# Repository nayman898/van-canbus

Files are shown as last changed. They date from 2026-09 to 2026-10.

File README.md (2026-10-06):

# Van CAN bus

A build-in-progress engine monitoring system for a **1982 Ford E-350**.
This repository contains the STM32 firmware, a laptop dashboard, and wiring
notes so others can follow along with the build.

The native [Android dashboard](android-app/README.md) connects a BTT U2C
directly to a phone or head unit over USB Host, without requiring a laptop or
Raspberry Pi in the vehicle.

[GitHub Actions](docs/automation.md) tests the host tools and CAN encoders,
builds both firmware configurations and the Android APK, and publishes the
generated wiki after successful pushes to `main`. Build downloads are attached
to each workflow run.

The first node uses an ST NUCLEO-G0B1RE and an Adafruit CAN Pal transceiver.
A BTT U2C V2.1 connects the bus to either the Android app or laptop. This is a
custom telemetry network, not an OBD-II scanner or decoder for a factory
vehicle network.

The current bench firmware transmits a Classical CAN heartbeat and two TX3
coolant-temperature inputs (pre- and post-radiator) at 500 kbit/s.

The provisional vehicle wiring and connector allocation are documented in
[the engine-node harness plan](docs/engine-node-harness.md).
It does not control the engine, fuel system, cooling fans, or any other output.
The node actively transmits its own CAN messages; “read-only engine monitoring”
does not mean CAN listen-only mode.

## How it fits together

```mermaid
flowchart LR
    TX3[TX3 coolant sensor] -->|Analog voltage| MCU[NUCLEO-G0B1RE]
    MCU -->|CAN TX / RX| PAL[Adafruit CAN Pal]
    PAL <-->|CAN-H / CAN-L + ground| U2C[BTT U2C V2.1]
    U2C <-->|USB| HOST[Android app or laptop dashboard]
```

The Nucleo samples the sensor and encodes the messages. The CAN Pal provides
the physical CAN interface; the U2C bridges the bus to Android or the laptop.
The working bench setup uses USB power for the Nucleo and U2C.

## Current status

| Area | What exists today |
| --- | --- |
| CAN and coolant channel 1 | Working on the bench at 500 kbit/s |
| Android app | Native U2C dashboard, raw-frame view, and CSV logging |
| Laptop tools | Terminal monitor and live browser dashboard |
| Vehicle harness | Provisional 6-pin power/CAN and 12-pin sensor allocations |
| Vehicle power | Protection parts selected; assembly/vehicle validation still pending in the build notes |
| Coolant channel 2 | Two-channel firmware flashed/verified; phone operation confirmed and both readings received on PC |
| Additional sensors | Pressure inputs planned |
| Recording | Raw-frame CSV recording and export in the Android app |

## Follow the build

| Guide | What it covers |
| --- | --- |
| [Documentation index](docs/README.md) | Suggested reading and build order |
| [Build progress](docs/build-progress.md) | Completed milestones, design choices, and next steps |
| [Hardware](docs/hardware.md) | Bench parts, sensor circuit, and hardware references |
| [Bench setup](docs/bench-setup.md) | Wiring, first power-up, expected readings, and troubleshooting |
| [Harness and vehicle power](docs/engine-node-harness.md) | Connector assignments and staged power-input work |
| [Firmware](docs/firmware.md) | Build, programming, and source walkthrough |
| [CAN protocol](docs/can-protocol.md) | Message layouts, units, fault flags, and examples |
| [Laptop tools](tools/README.md) | Dashboard, terminal monitor, setup, and limitations |
| [Android app](android-app/README.md) | Direct U2C connection, phone setup, and logging |

## Bench wiring

| Nucleo / CAN Pal | Connection |
| --- | --- |
| Nucleo 3V3 | CAN Pal Vcc |
| Nucleo GND | CAN Pal GND |
| Nucleo PA12 / FDCAN1_TX | CAN Pal TX |
| Nucleo PA11 / FDCAN1_RX | CAN Pal RX |
| CAN Pal SLNT | GND |
| CAN Pal H | U2C H |
| CAN Pal L | U2C L |
| CAN Pal terminal GND | U2C GND |

Leave the U2C V+ terminal disconnected. Enable one 120-ohm terminator at each
end. With all USB cables unplugged, CAN-H to CAN-L should measure about 60 ohms.

## Firmware behavior

- Bus: Classical CAN, 500 kbit/s
- Heartbeat identifier: standard 11-bit ID `0x100`
- Period: 500 ms
- Payload: protocol, node, status, sequence, and 32-bit little-endian uptime
- Nucleo LED PA5 toggles whenever a heartbeat is successfully queued
- Coolant identifiers: `0x110` pre-radiator, `0x111` post-radiator (standard 11-bit)
- Coolant period: 250 ms per sensor
- Coolant inputs: pre-radiator A0 / PA0 / ADC1_IN0; post-radiator A1 / PA1 / ADC1_IN1
- TX3 pull-up: nominal 2.47 kohm to 3.3 V

| Byte | Meaning |
| ---: | --- |
| 0 | Protocol version (`1`) |
| 1 | Node type (`1` = engine node) |
| 2 | Status (`0x01` = bench-test firmware) |
| 3 | Rolling sequence counter |
| 4-7 | Uptime in milliseconds, little-endian |

Coolant frames `0x110` and `0x111`:

| Byte | Meaning |
| ---: | --- |
| 0 | Protocol version (`1`) |
| 1 | Sensor (`1` = pre-radiator, `2` = post-radiator) |
| 2 | Status (`0` valid, bit 0 open, bit 1 short, bit 2 ADC, bit 3 calculation) |
| 3 | Rolling sequence counter |
| 4-5 | Averaged 12-bit ADC count, little-endian |
| 6-7 | Signed temperature in 0.1 degrees C, little-endian; `-32768` if invalid |

The temperature conversion uses a three-point Steinhart-Hart fit for the TX3:
9335 ohms at 0 C, 3500 ohms at 20 C, and 336 ohms at 80 C. Update
`TX3_PULLUP_OHMS` in `Inc/tx3_sensor.h` if the measured pull-up differs from
2470 ohms.

## Clone and build

Clone the repository, then initialize the pinned STM32CubeG0 dependency and
only the two nested ST driver modules this firmware uses:

```powershell
git clone https://github.com/nayman898/van-canbus.git
cd van-canbus
git submodule update --init --depth 1 third_party/STM32CubeG0
git -C third_party/STM32CubeG0 submodule update --init --depth 1 Drivers/STM32G0xx_HAL_Driver Drivers/CMSIS/Device/ST/STM32G0xx
```

From STM32CubeIDE for VS Code, select the `Debug` CMake preset and build. The
build creates `.elf`, `.hex`, and `.bin` images under `build/Debug`.

## Laptop monitor

Install Python 3.10 or newer, create a virtual environment, and install the monitor's
dependencies:

```powershell
py -3 -m venv .venv
.\.venv\Scripts\python -m pip install -r requirements.txt
.\.venv\Scripts\python tools\monitor_can.py
```

The U2C must use its normal `CAN OUT` H/L/GND connection and its `120R` jumper.

For a graphical dashboard, run:

```powershell
.\.venv\Scripts\python tools\can_dashboard.py
```

The dashboard opens at `http://127.0.0.1:8765` and displays live coolant
temperature, ADC voltage, sensor faults, node uptime, and CAN connection state.
It automatically retries if the USB CAN adapter is temporarily disconnected.
On Windows, `start_dashboard.bat` provides a one-click launcher after the Python
environment has been installed.

The dashboard displays live readings and retains the latest values in memory;
it does not save recordings. See the [tools guide](tools/README.md) for options,
troubleshooting, and a way to capture a basic terminal transcript.

Run the host-side protocol decoder tests with:

```powershell
.\.venv\Scripts\python -m unittest discover -s tests -v
```

## Safety boundary

This is bench-test firmware. Do not connect the RECOM regulator directly to
vehicle power until fused input, reverse-polarity protection, and automotive
transient/load-dump protection have been added and verified.
Sensor-input transient protection and a secured harness/enclosure are also
still needed before vehicle installation.

## Questions and build feedback

Questions and observations are welcome in
[GitHub Issues](https://github.com/nayman898/van-canbus/issues). Include the board
and adapter versions, firmware commit, wiring, and observed behavior so your
setup can be compared with this one.

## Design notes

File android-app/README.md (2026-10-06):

# Van CAN Android dashboard

Native, receive-only Android dashboard for the van's project-owned CAN network.
It connects directly to the BTT U2C over Android USB Host, so the first version
does not require a laptop or Raspberry Pi in the vehicle.

## Current capabilities

- Direct GS_USB/candleLight connection to the U2C at **500 kbit/s**.
- Decodes engine heartbeat `0x100`, pre-radiator coolant `0x110`, and
  post-radiator coolant `0x111` (both TX3 sensors).
- Shows two independent temperature cards, stacked on phones and side-by-side
  in wide landscape layouts; fault and stale status are per sensor.
- Shows coolant in °F/°C, ADC count, estimated signal voltage, node uptime,
  frame rate, heartbeat sequence, and recent raw CAN frames.
- Records every received frame to CSV and exports it with Android's document
  picker.
- Responsive custom dashboard for a phone in portrait or the ESSGOO display in
  landscape.
- System-bar and camera-cutout spacing, larger phone readings and controls,
  compact sensor/node cards, and scrolling when the window is too short.
- Requires no Google services and no third-party runtime library.

The application never submits a CAN data frame. The U2C is deliberately started
in normal CAN mode—not listen-only—because it must provide the CAN ACK bit when
the Nucleo and U2C are the only two active nodes.

## Open and run it

### Install a built APK

From a successful GitHub Actions run, download `android-debug-<commit>` and
extract `app-debug.apk` (see [build downloads](../docs/automation.md#download-a-build)).
Copy the APK to the phone, open it, and allow installation from that source
when Android prompts. This is a debug/test app, not a Play Store release.
The supported minimum is Android 8.0 / API 26.

To update an existing installation, the signing key must match. If Android
reports a signature conflict, export any logs before uninstalling the old app:
uninstalling removes its private files. See [debug signing](../docs/automation.md#android-signing-for-repeated-phone-updates).

### Build from Android Studio

1. In Android Studio, select **Open** and choose the `android-app` directory.
2. Allow the initial Gradle sync to finish.
3. On the Pixel, enable **Developer options → Wireless debugging**.
4. In Android Studio, choose **Pair Devices Using Wi-Fi** and pair the Pixel.
5. Select the Pixel as the run target and press **Run**.

Wireless debugging keeps the Pixel's USB-C port free for the U2C. The generated
debug APK is at:

```text
app/build/outputs/apk/debug/app-debug.apk
```

## First hardware test

1. With power off, verify approximately 60 Ω between CAN-H and CAN-L on the
   complete, terminated bus.
2. Connect the U2C to CAN-H, CAN-L, and the bus reference/ground used by the
   existing bench setup. Leave the U2C `V+` terminal disconnected.
3. Disconnect the U2C from the laptop.
4. Connect it to the Pixel using a known data-capable USB-C cable. If a direct
   cable does not put the phone into USB-host mode, use a USB-C OTG/host adapter.
5. Launch **Van CAN** and grant the Android USB permission prompt.
6. Power the Nucleo setup. The status should progress from `U2C ONLINE · WAITING
   FOR CAN` to `CAN ONLINE · 500 KBIT/S` and the raw-frame list should show
   `100`, `110`, and `111` with the two-channel firmware.

Both channels were confirmed operating in the October 5–6, 2026 bench session;
this does not establish ESSGOO compatibility or calibrated temperature accuracy.
Each card hides stale temperatures after 1.5 seconds without its own message.
An absent sensor with its pull-up installed should report OPEN without
interrupting the other channel. See the [bench test](../docs/bench-setup.md#second-coolant-channel).

Do not connect vehicle 12 V to any U2C USB or `V+` pin. The U2C is powered from
the Android USB host for this arrangement.

## Logging

Press **START LOG** to create a CSV in the app's private external-files folder.
Press **STOP LOG** to finish it. **EXPORT** opens Android's document picker and
copies the latest log to a location you choose. Export also safely stops an
active log first.

Both coolant IDs are included automatically in the raw-frame CSV; no separate
logging channel needs to be enabled for the post-radiator sensor.

## Reading the dashboard

| Display | Meaning |
| --- | --- |
| Pre-radiator / `0x110` | Sensor 1, engine outlet, A0/PA0 |
| Post-radiator / `0x111` | Sensor 2, radiator outlet, A1/PA1 |
| °F / °C | Firmware-calculated temperature, not independently calibrated by the app |
| ADC / V | Averaged raw ADC count and voltage estimated using a nominal 3.3 V reference |
| VALID | Fresh message with valid protocol, identity, ADC range, and no sensor fault |
| OPEN / SHORT | Firmware input fault; temperature is hidden |
| ADC ERROR / CALC ERROR | Acquisition or conversion failed; temperature is hidden |
| STALE / NO DATA | No fresh message for this sensor, or USB is disconnected |
| Engine node | Heartbeat status, node uptime, frame count/rate, heartbeat sequence |
| Raw CAN | Recent frames, including `100`, `110`, and `111` |

The header reports overall traffic; one healthy sensor does not establish that
the other is fresh. On a quiet bus, expect roughly ten received frames/second.
The controls are **CONNECT/DISCONNECT**, **START/STOP LOG**, and **EXPORT**.
On shorter screens, scroll to reach the raw frames and controls. No fan or
engine-control commands are implemented by this app.

## Troubleshooting

| Problem | Check |
| --- | --- |
| U2C not detected | USB data cable, host/OTG mode, supported USB identity, and connection to this device rather than the PC |
| USB permission denied | Reconnect, press CONNECT, and grant Android's USB permission |
| U2C online but waiting for CAN | Node power, shared reference, 500-kbit/s bus, wiring, and termination |
| Only pre-radiator appears | Install the two-card app build; flash the two-channel firmware and check for `111` in Raw CAN |
| Post-radiator shows OPEN | Check sensor 2 wiring/return and its separate divider; an installed pull-up without a sensor produces OPEN |
| One card becomes stale while the other updates | Check whether that channel's CAN ID continues arriving; freshness is independent |
| Works on phone but not PC | Move the U2C to the PC and restart the [Python dashboard backend](../tools/README.md#restart-after-updating-the-code) |
| APK will not update existing app | Check signing-key compatibility; export logs before any uninstall |
| Head-unit USB works for Android Auto but not Van CAN | The vendor may reserve that port; ordinary app USB Host access is not yet confirmed |

For resistance/continuity checks, remove power first and follow the
[bench guide](../docs/bench-setup.md). A functioning display does not validate
automotive power protection or temperature accuracy.

## ESSGOO head-unit test

Build and verify on the Pixel first, then copy/install the same APK on the
ESSGOO unit. Android version differences are covered by the app's API 26 minimum.
The remaining unknown is whether the ESSGOO firmware exposes its rear Android
Auto USB port to ordinary USB Host applications. The app will show `U2C not
detected` if that port is reserved by the vendor firmware.

## USB identities

Automatic detection currently accepts the two standard GS_USB identities:

| VID:PID | Family |
| --- | --- |
| `1D50:606F` | Geschwister Schneider / common GS_USB |
| `1209:2323` | candleLight |

If the BTT firmware reports a different identity, capture it with Android's
USB Device Info app or `adb shell dumpsys usb`, then add it in both
`GsUsbCanAdapter.isSupported()` and `res/xml/usb_device_filter.xml`.

## Project layout

- `MainActivity.java` — permission, USB lifecycle, decoding, logging, export.
- `usb/GsUsbCanAdapter.java` — direct GS_USB control and bulk transfers.
- `protocol/VanCanDecoder.java` — project CAN payload decoder.
- `DashboardView.java` — phone/head-unit responsive display.
- `logging/CsvCanLogger.java` — raw-frame CSV logger.

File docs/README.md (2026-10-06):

# Build documentation

[Project home](../README.md)

These notes describe the engine-monitoring system as it is being built. A
working bench circuit, a proposed vehicle circuit, and a reserved connector pin
are different stages of the project; each guide identifies which it describes.

## If you want to see how it is being built

Start with [build progress](build-progress.md), then read the
[hardware guide](hardware.md) and [harness plan](engine-node-harness.md).
They cover the parts, the first sensor circuit, the two-plug layout, and the
work still needed before installation.

## If you want to reproduce the bench setup

1. Gather the [bench hardware](hardware.md#bench-parts).
2. Clone and build the [firmware](firmware.md).
3. Follow the [bench wiring and bring-up](bench-setup.md).
4. Install and start the [laptop tools](../tools/README.md).
5. Compare the readings with the [CAN protocol](can-protocol.md).

For direct phone viewing without a PC or Pi, use the
[Android app guide](../android-app/README.md): APK installation, U2C connection,
two-temperature display, CSV logging/export, and troubleshooting. In the wiki,
this is the **Android dashboard** sidebar entry (`Android-App`).

Vehicle-power tests are a later stage in the [harness plan](engine-node-harness.md),
not a prerequisite for reproducing the USB-powered bench network.

## Where to find each kind of information

| Information | Maintained in |
| --- | --- |
| Parts and sensor circuit | [Hardware](hardware.md) |
| Board-to-board bench wiring | [Bench setup](bench-setup.md) |
| External connector cavity assignments | [Harness plan](engine-node-harness.md) |
| Firmware build and source organization | [Firmware](firmware.md) |
| CAN IDs and byte layouts | [CAN protocol](can-protocol.md) |
| Python commands and dashboard behavior | [Laptop tools](../tools/README.md) |
| Completed work and open design decisions | [Build progress](build-progress.md) |
| Phone dashboard and CSV recording | [Android app](../android-app/README.md) |
| Automated tests, build downloads, and maintenance | [Automation](automation.md) |
| Generated GitHub wiki | [Wiki publishing](wiki-publishing.md) |

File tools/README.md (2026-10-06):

# Laptop monitor and dashboard

[Project home](../README.md) · [Bench setup](../docs/bench-setup.md) · [Protocol](../docs/can-protocol.md)

The Python tools read the project's CAN messages through a BTT U2C V2.1 using
the `gs_usb` interface. Windows is the documented working host setup. The
adapter needs compatible firmware and a USB backend/driver accessible to
PyUSB; the tools do not flash the adapter or install its Windows driver.

## Install on Windows

Use Python 3.10 or newer. Run these commands from the repository root in
PowerShell:

```powershell
py -3 -m venv .venv
.\.venv\Scripts\python -m pip install -r requirements.txt
```

The requirements pin `python-can[gs-usb]` and `libusb-package`. The monitor
initializes the bundled libusb backend before loading the CAN interface, so
Windows does not need to provide that DLL itself. This does not replace the
USB device driver requirement.

## Browser dashboard

```powershell
.\.venv\Scripts\python tools\can_dashboard.py
```

After the first setup, double-click `start_dashboard.bat` to run the same app.
It serves the dashboard on `http://127.0.0.1:8765` and opens the default browser.
Keep its terminal open while using it; press **Ctrl+C** there to stop the server
and release the adapter. Closing the browser tab alone does not stop the app.

The dashboard displays both pre-radiator (`0x110`) and post-radiator (`0x111`)
coolant temperatures in °F/°C, independent fault/stale status, estimated sensor voltage,
ADC count, sensor faults, heartbeat uptime/sequence, frame count, and the age
of the last received frame. The browser polls the backend every 250 ms.

| Connection label | Meaning |
| --- | --- |
| `CAN live` | Adapter connected and a frame received within the last 1.5 seconds |
| `Waiting for CAN data` | Adapter connected, but no recent frame |
| `U2C disconnected` | The backend could not open or continue reading the adapter |
| `Dashboard backend unavailable` | Browser could not fetch the local server state |

The backend retries adapter errors every two seconds. Each temperature card
tracks its own message age and hides its temperature after 1.5 seconds without
an update, on a sensor fault, or when disconnected. Backend fetch failures
also clear both displayed temperatures. Traffic from one sensor does not keep
the other sensor's reading fresh. The header follows overall CAN traffic.

### Restart after updating the code

Stop the existing dashboard with **Ctrl+C in its terminal**, then launch
`start_dashboard.bat` again and refresh the browser. Refreshing or closing a
browser tab does not restart Python or load changed backend code. Run only
one dashboard/monitor against the U2C at a time, and move its USB connection
from the phone to the PC when switching hosts.

At `http://127.0.0.1:8765/api/state`, the two-channel backend has `coolant`
(pre-radiator) and `coolant_post` (post-radiator), each with `valid` and
`age_ms`. A response lacking `coolant_post` indicates old backend code.
On a quiet healthy bus, expect about ten frames/s: four per sensor plus
two heartbeats. Check that frame count rises and ages stay low, rather than
trusting an old `connected: true` value alone.

## Terminal monitor

Stop the dashboard first, then run:

```powershell
.\.venv\Scripts\python tools\monitor_can.py
```

It prints received timestamps, decoded heartbeat/coolant messages, and other
frames in python-can's text format. Press **Ctrl+C** to stop it. Unlike the
dashboard, the terminal monitor exits on adapter errors instead of retrying.

## Options

Both tools accept:

| Option | Default | Purpose |
| --- | --- | --- |
| `--bitrate` | `500000` | CAN bus bitrate; must match the node |
| `--index` | `0` | gs_usb adapter index |

The dashboard also accepts:

| Option | Default | Purpose |
| --- | --- | --- |
| `--host` | `127.0.0.1` | HTTP bind address |
| `--port` | `8765` | HTTP port |
| `--no-browser` | Off | Run without automatically opening a browser |

Example, using another HTTP port:

```powershell
.\.venv\Scripts\python tools\can_dashboard.py --port 8766 --no-browser
```

The server is local-only by default and has no authentication. Keep that
default for the laptop bench setup.

## Live monitoring and recording

The dashboard stores only its latest readings and session counters in memory.
It does **not** save a CSV, raw CAN log, or replayable recording. The terminal
monitor likewise prints to the console without creating a file.

For a basic text transcript, PowerShell can capture the terminal output:

```powershell
.\.venv\Scripts\python -u tools\monitor_can.py | Tee-Object -FilePath can-session.txt
```

Use a new filename for each session; this command overwrites that filename.
This is decoded console output, not a structured CAN recording or a playback
format. Do not run it alongside the dashboard against the same adapter.

## Troubleshooting

| Problem | Next check |
| --- | --- |
| Missing Python module | Install requirements with the same `.venv` interpreter used to launch the tool |
| Bundled libusb backend could not be loaded | Reinstall the pinned requirements and check Python/package compatibility |
| Adapter unavailable | Check USB data cable, compatible adapter firmware/driver, index, and other running CAN apps |
| Port already in use | Open the existing dashboard, stop its terminal, or choose another HTTP port |
| Server works but no frames | Follow the wiring, termination, and bitrate checks in the bench guide |
| Need the adapter's error details | Inspect `http://127.0.0.1:8765/api/state`; the backend includes an `error` field |

The scripts currently select `gs_usb` explicitly. A Linux SocketCAN setup or
Raspberry Pi deployment would need its own documented configuration; there is
no `--interface socketcan` option in these tools today.

## Decoder tests

From the repository root:

```powershell
.\.venv\Scripts\python -m unittest discover -s tests -v
```

The tests decode fixed payloads without opening the USB adapter. They still
require the installed Python dependencies because they import the monitor.

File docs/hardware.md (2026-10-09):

# Engine-node hardware

[Documentation index](README.md) · [Next: bench setup](bench-setup.md)

The first node uses development boards and a small discrete sensor circuit.
There is no custom PCB or finalized enclosure design in this repository yet.

## Bench parts

| Quantity | Part | Role |
| ---: | --- | --- |
| 1 | ST NUCLEO-G0B1RE | Runs the firmware and samples the sensor |
| 1 | Adafruit CAN Pal | Connects the MCU's CAN peripheral to the CAN wires |
| 1 | BTT U2C V2.1 with candleLight/gs_usb-compatible firmware | Laptop USB-to-CAN interface |
| 2 | TX3 coolant thermistors | Pre-radiator and post-radiator inputs |
| 2 each | 2.00 kohm and 470 ohm resistors | Separate nominal 2.47 kohm pull-up for each sensor |
| 2 | 1 kohm resistors | Separate series resistor into A0 and A1 |
| 2 | 100 nF ceramic capacitors | ADC input filtering to ground, one per channel |
| 2 total | 120-ohm CAN terminators | One at each bus end; use the boards' termination facilities |
| As needed | USB data cables, hookup wire, prototyping board | Power, programming, and assembly |
| 1 | Multimeter | Continuity, resistance, and voltage checks |

The two terminators are the total for this bench bus, not two extra resistors
to add when board termination is already enabled. Detailed interconnects are in
[bench setup](bench-setup.md).

## First coolant input

The TX3 is used as a two-wire thermistor. Its resistance and the pull-up form a
voltage divider. The MCU reads the divider through a 1-kohm series resistor.

```text
Nucleo 3V3
    |
  2.00 kohm
    |
   470 ohm
    |
    +-------- 1 kohm -------- A0 / PA0 / ADC1_IN0
    |
 TX3 thermistor
    |
dedicated sensor return ----- Nucleo GND
```

This is the bench circuit. The 1-kohm resistor alone is not a complete
automotive transient-protection circuit. The vehicle sensor-input protection
is still to be designed and added.

The thermistor itself is not polarized. Keep a consistent signal/return wire
assignment, with the return carried back to the engine node rather than using
the engine block as the sensor return. The reserved 5 V supply in the future
sensor connector is for active sensors; this TX3 divider uses **3.3 V**.

The current code assumes a 2470-ohm pull-up. If the measured combination differs,
update `TX3_PULLUP_OHMS` in [tx3_sensor.h](../Inc/tx3_sensor.h). The conversion
in [tx3_sensor.c](../Src/tx3_sensor.c) uses these three fit points:

| Temperature | Resistance used by the firmware fit |
| ---: | ---: |
| 0 °C | 9335 ohms |
| 20 °C | 3500 ohms |
| 80 °C | 336 ohms |

These are the project's current calibration assumptions, not a guarantee for
every replacement sensor. Compare your sensor with an independent temperature
measurement before relying on its readings. The firmware averages 32 ADC
samples and reports both the raw count and calculated temperature.

## Second coolant input

Duplicate the first divider on **A1/PA1/ADC1_IN1** for post-radiator coolant.
Do not share its signal junction or pull-up with A0. Both sensors use the same
conversion constants and nominal pull-up value. Add the 100 nF filter from
each ADC pin to ground, after that channel's 1-kohm series resistor.
See [second-channel wiring and tests](bench-setup.md#second-coolant-channel).

## Vehicle hardware in preparation

The [harness plan](engine-node-harness.md) contains the purchased power-stage
parts and staged test procedure: series diode, surge resistor, TVS, input
capacitors, and a RECOM R-78K5.0-1.0 converter. Their selection is not a record
of completed vehicle-transient testing.

The intended external connections are:

- **C1, 6-pin:** power, ground, CAN-H, CAN-L, reserved wake, and a spare.
- **C2, 12-pin:** coolant inputs/returns, future active-sensor power/return,
  pressure signals, and spares.

Both connector sizes are now available for the build. Their exact housing part
numbers, contact selection, face orientation, and mounting details still need
to be recorded. Follow the provisional cavity tables in the harness plan; do
not infer physical cavity positions from a generic connector picture.

Both TX3 channels are implemented and bench reception is confirmed. GlowShift
pressure inputs remain planned; reserved pins do not imply working pressure
input circuits or firmware support.

## Printable bottom guards — first fit prototypes

These are **open-top bench guards**, not sealed, automotive-qualified boxes.
They protect the underside from a flat work surface; open sides/top do not
exclude loose wire strands, tools, moisture, or metal debris. Remove the board
before soldering, drilling, or tapping plastic. Do not pot the electronics or
lay solder joints directly on the floor.

Top-view preview of the printable guards

| Board | Printable file | Dimensions / mounting |
| --- | --- | --- |
| EPLZON pictured 1.5 × 2 inch board | [Bottom tray STL](../hardware/protective-plates/stl/eplzon_38x51_tray.stl) | 43.3 × 56 × 8.4 mm; two central M3 locations, 40.6 mm apart |
| Adafruit Perma-Proto half, product 1609 | [Bottom tray STL](../hardware/protective-plates/stl/permaproto_half_1609_tray.stl) | 56 × 86.48 × 8.4 mm; two M3 locations, 73.66 mm apart |
| Nucleo MB1360, intact ST-Link, measured 8 mm pins | [Edge-retaining tray STL](../hardware/protective-plates/stl/nucleo_edge_tray_8mm_pins.stl) | 88 × 89.5 × 15.6 mm; 70 × 82.5 mm PCB, no board screws |
| Nucleo removable front stops | [Left STL](../hardware/protective-plates/stl/nucleo_stop_left.stl), [right STL](../hardware/protective-plates/stl/nucleo_stop_right.stl) | Print one each; two M3 × 6 mm screws into the tray, not the PCB |

All dimensions are millimetres. Import at **100% scale**, flat bottom on the
bed, with posts/spacers upright. The proto trays provide 6 mm from floor top
to PCB underside, a 2.4 mm floor, 2 mm low guards, and 12 mm wire notches on
all sides. Wires can also leave over the low rim. These notches are not strain
relief: secure cables separately without pulling on solder joints.

### Print and fit the proto trays

1. Print the small [EPLZON hole-spacing test](../hardware/protective-plates/stl/eplzon_38x51_fit_test.stl)
   and [Perma-Proto hole-spacing test](../hardware/protective-plates/stl/permaproto_half_1609_fit_test.stl)
   first. They are 1.2 mm-thick rails for checking hole alignment and pilot-hole
   print quality, **not electrical bottom protectors**. Check against the
   unpowered board's component side or use a paper template so the rail does
   not press on solder joints.
2. Print the full tray in ordinary, non-conductive **PETG for the bench**.
   Start with a 0.4 mm nozzle, 0.20 mm layers, four walls, five top/bottom
   layers, 20–30% infill, no supports. Use your filament maker's temperature
   profile and your CC2's calibrated flow settings; no printer-specific G-code
   is supplied. Use a brim if needed for adhesion.
3. Posts have **2.7 mm blind pilots**, intended for gently tapping M3 threads
   or carefully forming them with a machine screw. Test on scrap first.
   Start with M3 × 6 mm screws for a nominal 1.6 mm PCB; verify actual engagement
   and do not bottom out. Prefer nylon screws; if using metal, ensure the head
   and any washer stay within the mechanical-hole keepout. Do not overtighten.
4. The EPLZON tray uses the two **central 3.2 mm holes**, NOT the four M2 corner
   holes. The mounting posts touch a 6 mm-diameter area around each hole: check
   that this area has no soldered lead or component on your actual board.
5. Measure the longest underside solder/wire projection. With 6 mm supports,
   keep it below 4 mm to retain at least 2 mm of clearance. If it is longer,
   increase `clearance` in the model rather than forcing the board down.
6. Confirm the board is supported only at its mounting points, is not bowed,
   and does not rock. The two-post arrangement is a bench prototype, not
   validated support for heavy components or vehicle vibration.

### Nucleo: edge-retaining tray for 8 mm bottom pins

The user supplied the MB1360 mechanical drawing (70 × 82.5 mm) and measured
8 mm pin projection. The PCB underside is therefore **10 mm above the floor**,
leaving **2 mm nominal pin clearance**. Keep the ST-Link section attached.
There are no assumed PCB mounting holes: the rails support/capture its long
edges and two removable front corner stops prevent sliding out.

1. Print the [full-width rail-fit coupon](../hardware/protective-plates/stl/nucleo_rail_fit_test.stl)
   first. It has the same rail spacing, clearance, and 2.0 mm slot as the full
   tray, but is only 12 mm long. The slot assumes 1.6 mm PCB thickness plus
   0.4 mm vertical allowance; width clearance is 0.5 mm per side.
2. With **all power/cables removed**, inspect the outer 0.8 mm strip along both
   long edges, on both faces. It must be free of components, solder, wiring,
   and protruding header plastic where the lips/supports contact. Sideways
   board play can increase contact overlap to about 1.3 mm on one side; check
   that wider strip too. The supplied top drawing does not establish underside
   keepouts. Do not force the coupon or tray past a connector or solder joint.
3. Print the tray and one of each front stop, using the PETG settings above.
   Flat bases go on the bed; lips are only 1.3 mm overhangs and are intended to
   print without supports. Inspect the slicer's layers and remove any droop
   before test-fitting. Do not scale the entire model to correct a tight slot.
4. Before inserting the board, tap/check the tray's two 2.7 mm blind pilots.
   The rail opening is the end with the two low screw pads. Slide the **non-USB
   end first** toward the far stop, keeping the USB/ST-Link end at the opening.
   Headers, pins and solder joints must stay clear during the entire slide.
5. Install the left/right corner stops on their screw pads with **M3 × 6 mm**
   screws. Their raised tabs face inward and the open/USB end. They attach to
   plastic only and leave the central USB area open. Do not tighten them onto
   the board; leave its small designed clearance. Check the actual USB plug's
   moulded body clears the tray before plugging in.
6. Verify the lowest pin still clears the floor by at least 2 mm, the board
   cannot slide out or lift free, and no plastic contacts solder or components.
   Only then reconnect power. Remove both stops before sliding the PCB out.

Edit [nucleo.json](../hardware/protective-plates/nucleo.json) if the board
thickness, edge keepouts, or pin length differs. This is a **first-fit bench
prototype**, not physically verified or approved for vibration/underhood use.
The older drill-to-fit blank and separate spacers remain as legacy files; they
are not needed for this tray, and electrical header holes must never be used
as screw mounts. No drilling or cutting of the Nucleo is required.

### Material and enclosure limits

PETG is a practical first fit/bench material; ASA offers better heat/UV
resistance but needs suitable ventilation and a tuned enclosed-printer profile.
See the [manufacturer material guide](https://help.prusa3d.com/filament-material-guide).
Neither material name alone establishes suitability underhood: check the exact
filament datasheet, measured location temperature, hot components, fluid
exposure, and vibration. Avoid conductive/ESD filament. Keep hot diodes and
the surge resistor clear of plastic and maintain their thermal clearance.

Full lids and sealed cable entries are deferred until we measure the populated
component heights, wire bundle sizes, USB access, and mounting location. These
prints are not waterproof, flame-rated electrical enclosures, or a replacement
for the planned protected vehicle power stage.

### Editable source and verification

#### Fusion / Onshape solid CAD files

- [Nucleo STEP assembly — original 2.7 mm pilots](../hardware/protective-plates/step/pilot_2.70mm/nucleo_assembled.step)
- [Nucleo STEP assembly — 2.5 mm M3-tap pilots](../hardware/protective-plates/step/pilot_2.50mm/nucleo_assembled.step)

Each assembly's directory includes individual **STEP solids** for both proto trays, the Nucleo
tray and left/right stops, and the fit-test pieces. `nucleo_assembled.step`
contains the tray and stops in their assembled positions as three separate
solids; use individual part files when preparing prints. Each directory also
contains a validation report. Editable generator source/JSON and dependency
lists are in `hardware/protective-plates/`.

Generated ZIP bundles are excluded from Git because they duplicate the tracked
CAD files, sources, and hardware guide. The STEP and mount generators below
still create local ZIP bundles when you need to share a complete set.

These are analytic CAD bodies, not STL-to-solid conversions. STEP does **not**
preserve the original Fusion timeline, Onshape sketches/constraints, or named
parameters. Native `.f3d` / Onshape documents are not generated here. After
import, use direct face edits or add sketches and features, then save in your
application's native format. For linked dimensional changes, edit the supplied
JSON/source and regenerate instead of expecting imported feature history.

- **Fusion:** download and open/upload the desired `.step` as a CAD design
  (not Insert Mesh), edit the solid bodies, and save your own Fusion document.
- **Onshape:** import the downloaded `.step` into a document; edit its solid
  parts with direct-edit features or new sketches. See
  [Onshape's import/edit guide](https://www.onshape.com/en/resource-center/tech-tips/import-edit-step-iges-parasolid-stl).
- Units are **mm**. Check the Nucleo tray is 88 × 89.5 × 15.6 mm after import.

The 2.5 mm variant changes only the blind pilots and matching pilot test holes;
the stops' 3.3 mm clearance holes remain unchanged. It has no modelled threads:
finish the printed pilots to the tap manufacturer's drill size, then tap M3 ×
0.5 without breaking through the floor. Test blind-hole thread depth on scrap
and account for the tap's lead. STEP exports do not overwrite existing STLs;
export new STLs from CAD if printing the tap-size version.

To regenerate STEP (Python 3.12+, preferably in a separate virtual environment):

```sh
python -m pip install -r hardware/protective-plates/requirements-step.txt
python hardware/protective-plates/export_step.py
python hardware/protective-plates/export_step.py --pilot-diameter 2.5
```

[STEP exporter](../hardware/protective-plates/export_step.py) reuses the original
geometry recipe with an OpenCascade solid backend. Each exported part is
re-imported and checked for validity, solid count, volume, dimensions, and
analytic cylindrical holes. Assembly import is checked for three valid solids.
Fusion/Onshape UI import and physical print fit have not been tested here.

#### Parametric dimensions and STL regeneration

Board dimensions and hole coordinates are in [boards.json](../hardware/protective-plates/boards.json).
The image supplied for the EPLZON gives 38.1 × 50.8 mm and a central hole span
of 40.6 mm. The Perma-Proto uses the exact 81.28 × 50.8 mm outline and
73.66 mm span from [Adafruit's PCB layout](https://github.com/adafruit/Adafruit-Perma-Proto-PCB),
rather than rounded shop dimensions. Its long axis is Y in this model.
Physical board revision, solder clearance, and printer shrinkage still need
checking. Do not scale the whole part to change screw-hole size.

With Python 3.12+:

```sh
python -m pip install -r hardware/protective-plates/requirements.txt
python hardware/protective-plates/generate.py
```

[The generator](../hardware/protective-plates/generate.py) produces the STLs,
preview, and [validation report](../hardware/protective-plates/validation.json).
It checks each mesh for watertightness, consistent winding, positive volume,
a single connected solid, and placement on Z=0. The Nucleo tray and assembled
stops also pass collision checks against the nominal PCB and an 8 mm-deep
central pin envelope (excluding the edge-contact strips). **These are digital geometry
checks, not physical fit tests.**

## Hammond 1554UA2GY Nucleo carrier — V2

Use this revision instead of the sliding Nucleo tray above when mounting in
the Hammond case. The photos suggest the board was sitting above the old
rail channel, leaving the end stops too low. V2 removes the upper rail lips:
the board drops in vertically and two removable side retainers capture its
edges. It does **not** assume screw-hole positions in the Nucleo PCB.
The original V1 files and the two proto-board holders are unchanged.

- [Case mounting-pattern test STL](../hardware/protective-plates/hammond-v2/case_mount_fit_test.stl)
- [Carrier STL](../hardware/protective-plates/hammond-v2/carrier.stl)
- [Retainer STL — print TWO](../hardware/protective-plates/hammond-v2/retainer_print_two.stl)
- [Assembled STEP for Fusion / Onshape](../hardware/protective-plates/hammond-v2/assembled.step)
- [Parametric generator](../hardware/protective-plates/hammond_mount.py)
- [Validation results](../hardware/protective-plates/hammond-v2/validation.json)

The [Hammond mechanical drawing](https://www.hammfg.com/files/parts/pdf/1554UA2GY.pdf?v=1748872871)
identifies **four internal M3 brass inserts at 161.5 × 90 mm spacing**.
These are not the M4 lid inserts or the intermediate #6 self-tapping bosses.
The 170 × 104 × 2.4 mm carrier has four 3.6 mm clearance holes centered at
(4.25, 7), (4.25, 97), (165.75, 7), (165.75, 97), measured from one corner.
The narrower carrier avoids the lid-post corners; it is not a copy of the
full-size steel accessory panel. The Nucleo holder is shifted all the way to
the X=0 end: the outer retainer is flush with that plate edge, leaving an
80 × 104 mm area clear of the holder at the opposite end (apart from the case
mounting holes). PCB origin is (10, 10.75) mm, with its USB end facing Y=0.
All four case screws retain a 7 mm diameter vertical access envelope; use
heads/washers no larger than 7 mm. Route and strain-relieve cables separately.

### Print and fit sequence

1. Print **only the mounting-pattern test** first, flat at 100% scale.
   Check it drops onto the four internal brass-insert bosses without rocking,
   hitting the case walls, or needing screw force to align the holes.
2. Print the carrier flat and two retainers flat. Start with 0.2 mm layers,
   four walls and 30–40% infill; no supports are needed. PETG is suitable for
   bench fitting; ASA is a candidate for warmer service, but this design has
   no validated underhood temperature, vibration, or fire rating.
3. Clear the four **blind 2.5 mm pilot holes** with a depth-limited drill and
   tap M3 × 0.5. Usable pilot depth is 11.2 mm; do not drill through the floor.
   Remove all chips before placing electronics. Use four M3 × 8 mm pan-head
   screws for the retainers (5.6 mm nominal engagement through the 2.4 mm bar).
4. Drop the unpowered Nucleo onto the two narrow support edges. PCB underside
   is 10 mm above the carrier floor, giving the stated 8 mm pins 2 mm clearance.
   Confirm every pin and solder joint clears the floor and supports.
   **The outer 0.8 mm PCB edge strips must be free of pins/components**; this
   remains an unverified physical-fit assumption. Stop if either header rests
   on a rail, or the board cannot seat flat. Do not force it down.
5. Fit one retainer per side, with its overhanging edge facing the PCB. Rotate
   the second copy 180° in the plane. Two screws per bar prevent rotation.
   The design leaves 0.4 mm above a nominal 1.6 mm PCB; tighten against the
   printed posts, not against the PCB. The front corner stops and rear fence
   limit lengthwise movement. Check USB/header access before powering up.
6. Screw the carrier into the case's four **M3 brass inserts**. Hammond lists
   M3 × 8 mm screws for its panel, but our printed carrier has a different
   thickness: measure usable insert depth and select length/washer thickness
   so screws engage securely without bottoming. An M3 × 8 screw through this
   plate projects 5.6 mm before washers. Do not force a bottomed screw or use
   self-tappers in the brass inserts. No drilling through the case is required.

Check clearance to the lid with all headers, plugs and wiring installed;
board thickness, header geometry, printer shrinkage and the case itself still
need physical verification. This is a bench-fit prototype, not a certified
automotive mounting system. Mounting inside a rated case does not independently
establish a rating for the completed wired enclosure.

The STEP files contain editable analytic solids, not a native Fusion timeline
or Onshape feature tree. Import the assembly for placement or the individual
parts for direct face edits. To regenerate after changing the constants:

```sh
python -m pip install -r hardware/protective-plates/requirements-step.txt
python hardware/protective-plates/hammond_mount.py
```

The generator validates nominal PCB/pin and inter-part clearance, valid CAD
solids, STEP round trips, and watertight STL meshes. These checks do not replace
the mounting-pattern print and unpowered physical fit checks above.

## EPLZON holder with 5 × 5 mm corner contacts

This experimental alternative leaves all PCB mounting holes unused, for the
assembled board whose central holes are covered by wiring and a subboard.
Four supports and four removable corner clips overlap only the nominal
5 × 5 mm corner squares. Revised after the first print missed the corners
by approximately 1 mm: both the lower supports and upper clips now reach
3 mm farther inward than the original 2 mm version. Board spacing, screw
positions and underside clearance are unchanged; this corrects contact reach
without making the board pocket smaller. Reprint the tray/frame and four clips.
The user's clearance estimate is provisional:
**rounded PCB corners or corner holes may remove too much of that contact
area. Verify actual solid PCB material is captured before using this holder.**
Do not enlarge the contacts into wiring or solder joints to force a fit.

- [Fit-test frame](../hardware/protective-plates/eplzon-corners/fit_test_frame.stl)
- [Full bottom tray](../hardware/protective-plates/eplzon-corners/tray.stl)
- [Corner clip — print four](../hardware/protective-plates/eplzon-corners/corner_clip_print_four.stl)
- [Editable STEP assembly](../hardware/protective-plates/eplzon-corners/assembled.step)
- [Generator](../hardware/protective-plates/eplzon_corner_mount.py)

Print the fit-test frame and four clips first, flat, at 100% scale, 0.2 mm
layers and four walls. No supports are needed. Tap the eight blind 2.5 mm
post holes M3 × 0.5; two screws per clip prevent rotation. Use eight M3 × 6 mm
pan-head screws with heads no larger than 5.5 mm diameter, without washers
(3.6 mm engagement through the 2.4 mm clips). Pilot depth is
7.1 mm; depth-limit tools and clean out debris with the electronics removed.
Rotate identical clips to match each corner's two holes. Tighten against
the posts, never crush the PCB or wiring.

The tray is 54.1 × 66.8 mm with 6 mm free height under the board, except at
the four contact squares. PCB thickness is assumed to be 1.6 mm, with 0.3 mm
vertical retention clearance. Measure your longest underside solder joint
or wire: it must fit with margin in that 6 mm space. Check all four corners
seat and retain securely, without rocking or slipping past the clips. If
the rounded corners cannot be captured, stop and provide a photo for a
revised contact shape; this design is not yet physically validated.

After checking fit, substitute the solid-floor tray for underside protection.
The open frame is a fit test, not a bottom-contact guard. PETG is appropriate
for bench fitting; this is not a sealed or vehicle-qualified enclosure and
does not include mounting to the Hammond carrier. Existing center-hole trays
are unchanged. Regenerate with `python hardware/protective-plates/eplzon_corner_mount.py`
using the same STEP requirements as the Hammond holder.

## Manufacturer references

- [ST MB1360 / Nucleo-64 user manual](https://www.st.com/resource/en/user_manual/dm00452640.pdf): board power selection, connectors, and onboard ST-Link.
- [Adafruit CAN Pal pinouts](https://learn.adafruit.com/adafruit-can-pal/pinouts): transceiver pinouts and termination.

Check the documentation for your actual board revision when locating headers
or changing power jumpers.

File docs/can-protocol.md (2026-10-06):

# CAN protocol

[Documentation index](README.md) · [Firmware](firmware.md) · [Laptop tools](../tools/README.md)

This is the project's own telemetry format. The definitions are in
[can_protocol.h](../Inc/can_protocol.h) and the encoder in
[can_protocol.c](../Src/can_protocol.c).

## Bus and encoding

- Classical CAN at **500,000 bit/s**; CAN FD and bitrate switching disabled.
- Standard **11-bit** identifiers and eight-byte data payloads.
- Multi-byte integers are **little-endian**.
- Protocol version is `1`.
- Each message type has its own eight-bit sequence counter, wrapping after 255.
- Nominal periods assume normal operation; reception may be delayed or missing
  if transmission is blocked or the bus is unavailable.

## Engine heartbeat — `0x100`

Nominal period: **500 ms**.

| Byte | Field | Encoding |
| --- | --- | --- |
| 0 | Protocol version | `1` |
| 1 | Node type | `1` = engine node |
| 2 | Node status | `0x01` = bench-test firmware |
| 3 | Sequence | Unsigned eight-bit counter |
| 4–7 | Uptime | Unsigned 32-bit milliseconds since startup |

The uptime field wraps with the 32-bit tick counter. A restart resets the
uptime and sequence counters. The node status is a firmware-stage indicator,
not the coolant sensor's fault status.

Example from the decoder tests:

```text
ID 0x100    01 01 01 2A 78 56 34 12
Protocol 1, engine node 1, bench status 1, sequence 42
Uptime = 0x12345678 = 305419896 ms
```

## Coolant temperatures — `0x110` and `0x111`

Nominal period: **250 ms per sensor**, each with an independent sequence counter.

| Location | Sensor ID | CAN ID | ADC input |
| --- | --- | --- | --- |
| Pre-radiator (engine outlet) | 1 | `0x110` | A0 / PA0 / ADC1_IN0 |
| Post-radiator (radiator outlet) | 2 | `0x111` | A1 / PA1 / ADC1_IN1 |

Both are TX3 thermistors with separate 2.47-kohm pull-ups. Sensor 1 retains
its existing wire format; adding sensor 2 does not change protocol version.

| Byte | Field | Encoding |
| --- | --- | --- |
| 0 | Protocol version | `1` |
| 1 | Sensor ID | `1` = pre-radiator; `2` = post-radiator |
| 2 | Sensor status | Flags below; zero means valid |
| 3 | Sequence | Unsigned eight-bit counter |
| 4–5 | ADC reading | Unsigned 16-bit field containing the averaged 12-bit count |
| 6–7 | Temperature | Signed 16-bit integer in tenths of a degree Celsius |

On a fault, the firmware sends `-32768` (`00 80` in wire byte order) as the
invalid temperature value. Consumers should check status before displaying
temperature. Both host decoders validate status, protocol version, matching
CAN/sensor identity, ADC range, and the invalid-temperature sentinel. Each UI
tracks freshness per sensor and hides temperatures after 1.5 seconds without
that sensor's message, or when disconnected.

| Status | Meaning | Current firmware condition |
| --- | --- | --- |
| `0x00` | Valid | Conversion completed without a fault |
| `0x01` | Open circuit | ADC count >= 4050 |
| `0x02` | Short circuit | ADC count <= 16 |
| `0x04` | ADC error | ADC acquisition failed |
| `0x08` | Calculation error | Invalid/non-finite or unrepresentable conversion result |

Flags occupy individual bits, although the present firmware returns one fault
at a time. The host maps these individual values to labels; combined/unknown
values are shown as unknown status and still suppress temperature.

Example from the decoder tests:

```text
ID 0x110    01 01 00 07 32 08 0A 01
Protocol 1, sensor 1, valid, sequence 7
ADC = 0x0832 = 2098
Temperature = 0x010A = 266 tenths = 26.6 °C = 79.88 °F
```

The host's displayed voltage is `adc_raw * 3.3 / 4095`, using a nominal 3.3 V
reference. It is an estimate derived from the count, not a separate voltage
measurement. Temperature comes from the firmware's transmitted value.

For the same test reading on sensor 2, use `0x111` with payload
`01 02 00 07 32 08 0A 01`. An absent second sensor with its pull-up installed
reports an open-circuit fault; it does not suppress sensor 1.

## Planned expansion

Pressure inputs have no implemented message definitions yet.
Allocate their IDs and payloads alongside the firmware and
host changes, then update this reference. There is currently no DBC file,
configuration protocol, or vehicle-control message set.

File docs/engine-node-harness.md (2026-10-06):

# Engine node harness plan

[Documentation index](README.md) · [Bench setup](bench-setup.md) · [Hardware](hardware.md)

This is the preparation plan for the first read-only engine node. The bench
network already works at 500 kbit/s. Vehicle power and sensor inputs are not
ready to connect yet.

## Connector strategy

Keep vehicle power/CAN separate from the sensor harness. This leaves enough
sensor cavities for later oil and fuel-pressure inputs and makes either side of
the installation serviceable without disturbing the other.

Both the 6-pin and 12-pin plugs are now available for this build. The intended
allocation is [C1 for power/CAN](#c1-final-power-and-can-provisional-6-way) and
[C2 for sensors](#c2-final-sensors-provisional-12-way). Those cavity assignments
remain provisional until the housing part numbers and orientation are recorded.
The older C0 combined allocation below is retained as a temporary reference;
it is **not pin-compatible** with the sensor-only C2 allocation.

Connector names C1/C2 and capacitor references C1/C2 in the power schematic
belong to separate naming contexts in these prototype notes.

## C0: temporary combined 12-way

This was the interim allocation while the separate power/CAN connector was unavailable.
The molded cavity numbers on the connector are authoritative; do not assign
pins by apparent left/right position because the mating face and wire-entry
views are mirrored.

Typical cavity arrangement, viewed at the mating face and confirmed by the
molded numbers:

```text
  1    2    3    4    5    6
 12   11   10    9    8    7
```

| Cavity | Circuit | Suggested color | First van test |
| ---: | --- | --- | --- |
| 1 | Fused switched 12 V input | Red | **Leave unpopulated** |
| 2 | Coolant sensor 1 signal | Tan/white | TX3 at thermostat outlet |
| 3 | Coolant sensor 2 signal | Blue/white | Populate when channel 2 is built |
| 4 | Regulated 5 V sensor supply | Pink | Reserved; seal cavity |
| 5 | Ignition/wake input | Orange | Reserved; seal cavity |
| 6 | CAN-H | Yellow | Connect to U2C CAN-H |
| 7 | CAN-L | Green | Connect to U2C CAN-L |
| 8 | Spare analog/digital input | Violet | Reserved; seal cavity |
| 9 | Future active-sensor return | Gray/black | Reserved; seal cavity |
| 10 | Coolant sensor 2 return | Blue/black | Populate when channel 2 is built |
| 11 | Coolant sensor 1 return | Tan/black | Dedicated TX3 return to engine node |
| 12 | Module power/CAN reference ground | Black | Connect to U2C GND |

Pins 1/12, 2/11, 3/10, and 6/7 form vertically adjacent pairs. Keep the two
TX3 returns as dedicated conductors all the way to the module; join them to
circuit ground inside the enclosure, not at the engine or chassis. Twist pins
6 and 7 together. Carry pin 12 alongside the CAN pair as its reference.

For the first vehicle data test, power the Nucleo through USB and leave cavity
1 empty. The U2C `V+` terminal also remains disconnected. This makes the test
read-only and prevents raw vehicle power from reaching the prototype.

### Temporary harness preflight

1. Disconnect both USB cables and all vehicle connections.
2. Use continuity mode to prove every cavity end-to-end and prove that adjacent
   cavities are not shorted. Record the result by cavity number.
3. Confirm CAN-H reaches CAN-H, CAN-L reaches CAN-L, and pin 12 reaches the U2C
   ground terminal.
4. Enable one 120-ohm termination at the CAN Pal end and one at the U2C end.
   Measure approximately 60 ohms between cavities 6 and 7 with power removed.
5. Connect the two TX3 wires only to cavities 2 and 11. A TX3 thermistor is not
   polarized, but keep the assigned colors consistent at both ends.
6. Power the engine node by USB, start the dashboard, and verify heartbeat and
   room-temperature data before installing the harness in the van.

## Clean 12 V bench-supply test

This test validates the R-78K5.0 converter and external-power arrangement. It
does **not** validate an installation against reverse battery, alternator
transients, jump starts, or automotive load dump.

### Stage 1: converter by itself

1. Keep the Nucleo, CAN Pal, USB cables, and sensor board disconnected.
2. Verify the R-78K5.0 pin numbering against its datasheet before applying
   power. Do not rely on package orientation from memory.
3. Connect bench-supply positive through a small inline fuse to cavity 1 and
   supply negative to cavity 12. Use a 0.5 A fuse for this prototype test.
4. Set the supply to 12.0 V with a 0.10 A current limit, then switch it on.
5. Measure the converter input and output directly at its pins. Expect about
   12.0 V input and 5.0 V output. Switch off immediately for reversed polarity,
   current limiting, heat, odor, or an output outside 4.75--5.25 V.
6. Switch the supply off and wait for the output to fall before changing wiring.

### Stage 2: Nucleo from the converter

1. Configure Nucleo jumper JP2 to pins 5--6 for the `E5V` source, following the
   MB1360 board manual.
2. Connect converter 5 V output to the Nucleo `E5V` input and converter ground
   to Nucleo ground. Keep the ST-Link USB cable disconnected.
3. Set the bench supply to 12.0 V and a 0.25 A current limit. Power it on and
   verify 5 V and 3.3 V at the Nucleo headers before connecting the CAN Pal.
4. Connect the CAN Pal and confirm heartbeat through the independently powered
   U2C. Record steady-state input current for comparison after later changes.
5. If USB debugging is needed, apply external E5V power first and connect the
   ST-Link USB cable second, as required by the board manual.

The R-78K5.0-1.0 accepts 6.5--36 V and provides regulated 5 V at up to 1 A, but
it is not an automotive input-protection device. Do not proceed from this clean
bench test to van power until the fused reverse-polarity and transient/load-dump
stage has been selected, assembled, and tested.

## Selected protected vehicle-input stage

The following parts were purchased for the engine-node power input:

| Ref. | Part | Function |
| --- | --- | --- |
| D1 | STMicroelectronics `STPS5H100BY-TR` | 100 V, 5 A automotive Schottky series diode for reverse-battery protection |
| R1 | Vishay `PR02000201009JR500` | 10 ohm, 2 W axial surge-current limiting resistor |
| D2 | Vishay `SM8S18CAHM3/I` | 18 V standoff, 29.2 V maximum-clamp, bidirectional automotive TVS |
| C1 | Panasonic `EEH-AZC1H470B` | 47 uF, 50 V polarized hybrid input capacitor |
| C2 | TDK `FA18X7R1H104KNU00` | 0.1 uF, 50 V X7R ceramic input bypass capacitor |
| U1 | RECOM `R-78K5.0-1.0` | 6.5--36 V input to regulated 5 V converter |
| C3 | TDK `FA18X7R1H104KNU00` | 0.1 uF, 50 V ceramic output bypass capacitor |

Wire the stage in this order:

```text
switched vehicle +12 V
        |
   external 0.5 A fuse, close to source
        |
        +---- D1 anode
              D1 cathode/tab ---- R1 10 ohm ---- PROTECTED_12V ---- U1 pin 1 (+VIN)
                                                   |               U1 pin 2 (GND) ---- GND
                                                   |               U1 pin 3 (+VOUT) -- +5V
                                                   |
                                                   +---- D2 TVS ---- GND
                                                   +---- C1 47 uF -- GND
                                                   +---- C2 0.1 uF - GND

                                                     +5V ---- C3 0.1 uF ---- GND

vehicle ground -------------------------------------------------------------- GND
```

Important assembly details:

- D1's anode faces the fused vehicle input. Its cathode and metal DPAK tab face
  R1 and the converter. Confirm the physical leads with diode mode before
  soldering; the unused DPAK lead is not connected.
- D2 has a `CA` bidirectional suffix and can be installed either direction. Keep
  both of its connections short and heavy, directly between `PROTECTED_12V` and
  the power ground bus.
- C1 is polarized: positive goes to `PROTECTED_12V`, negative goes to ground.
  C2 and C3 are not polarized.
- The 10-ohm resistor intentionally limits surge current into the TVS. It also
  prevents using the converter's full nominal 1 A output at low input voltage;
  this stage is sized for the low-current engine-monitor node, not cabin loads.
- Keep CAN/sensor returns connected to the same module reference ground, but do
  not route their normal current through the TVS or capacitor lead lengths.

### Protected-input staged test

1. Disconnect the Nucleo, U2C, CAN wiring, sensors, and all USB cables.
2. With power off, verify no hard short from `PROTECTED_12V` or +5 V to ground.
3. Feed 12 V through the fuse with a 0.10 A bench current limit. Measure voltage
   before D1, after D1, at `PROTECTED_12V`, and at U1 pin 3. Expect a small drop
   across D1, almost no drop across R1 with no load, and about 5.0 V output.
4. Switch off, connect the Nucleo at E5V/GND, raise the limit to 0.25 A, and
   verify the 5 V and 3.3 V rails before reconnecting CAN.
5. For a reverse-polarity check, disconnect every USB/CAN connection, set the
   bench limit to 0.01 A, reverse the 12 V input, and verify zero converter
   output and no heating. Correct polarity before reconnecting anything.
6. Do not attempt to force the TVS into avalanche with the bench supply. Final
   installation still requires the fuse at the vehicle-power takeoff and secure,
   vibration-resistant support for the two surface-mount power parts.

### C1: final power and CAN (provisional 6-way)

| Cavity | Circuit | Suggested color |
| --- | --- | --- |
| 1 | Protected switched vehicle power | Red |
| 2 | Power ground | Black |
| 3 | CAN-H | Yellow |
| 4 | CAN-L | Green |
| 5 | Ignition/wake input, reserved | Orange |
| 6 | Spare | Violet |

The R-78K5.0 regulator must not be connected directly to vehicle power. Parts
for the protection stage are selected above; assembly and validation must
precede vehicle-power use. The table's “protected” power label does not settle
which side of C1 houses the protection stage. Record that physical placement
in the final wiring drawing before wiring cavity 1.

### C2: final sensors (provisional 12-way)

| Cavity | Circuit | Initial use |
| --- | --- | --- |
| 1 | Coolant sensor 1 signal | TX3 at thermostat outlet |
| 2 | Coolant sensor 1 return | Dedicated return to engine node |
| 3 | Coolant sensor 2 signal | TX3 at lower radiator hose |
| 4 | Coolant sensor 2 return | Dedicated return to engine node |
| 5 | Regulated 5 V sensor supply | Reserved for future active sensors |
| 6 | Active-sensor return | Reserved for future active sensors |
| 7 | Oil-pressure signal | Reserved; GlowShift interface TBD |
| 8 | EFI fuel-pressure signal | Reserved; GlowShift interface TBD |
| 9 | Carburetor fuel-pressure signal | Reserved; GlowShift interface TBD |
| 10 | Spare analog input | Reserved |
| 11 | Spare digital/frequency input | Reserved |
| 12 | Spare | Reserved |

Sensor 1 is **pre-radiator**, feeding the A0/PA0 divider; sensor 2 is
**post-radiator**, feeding its own identical divider on A1/PA1. Both use
2.47-kohm pull-ups to 3V3, separate 1-kohm ADC series resistors, and dedicated
sensor returns. See the [second-channel bench test](bench-setup.md#second-coolant-channel).
Do not confuse C2 cavities 3/4 with temporary C0 cavities 3/10.

The three GlowShift signals must not be connected until their gauge supply,
signal range, and grounding have been measured. The engine node will need a
high-impedance protected input so it does not alter the gauge readings.

## Work that is safe now

- Label both halves of each connector and all loose wires before assembly.
- Practice open-barrel crimps on spare contacts and scrap 18--22 AWG wire.
- Prepare an uncut length of twisted CAN wire. Keep CAN-H and CAN-L together at
  approximately one twist per 25 mm (one inch).
- Lay out the Nucleo, CAN Pal, and Perma-Proto inside the enclosure and measure
  for a removable ASA mounting tray.
- Plan for the enclosure vent to face downward when installed.
- Keep a service loop at the enclosure rather than cutting the vehicle harness
  to its final length on the bench.

## Work to defer

- Do not solder Deutsch/AT-series crimp contacts. Crimp them only; solder can
  wick up the conductor and create a vibration failure point.
- The first TX3 bench channel uses a nominal 2.47-kohm pull-up to 3.3 V, a
  1-kohm series resistor into A0/PA0, and firmware open/short detection. Add
  automotive transient clamps before vehicle installation.
- Do not drill the enclosure until the connector housing part numbers,
  orientation, mounting tray, and cable-exit direction are confirmed.
- Do not connect the R-78K5.0 regulator or Nucleo directly to van power.
- Do not connect or tap the GlowShift pressure-sensor wiring yet.

## Bench wiring retained for the next test

| Nucleo | CAN Pal |
| --- | --- |
| 3V3 | Vcc |
| GND | GND and SLNT |
| PA12 / FDCAN1_TX | TX |
| PA11 / FDCAN1_RX | RX |

Continue powering the Nucleo by USB for bench testing. The first TX3 channel has
been verified at 1.69 V with a room-temperature sensor near 2.60 kohm. The
vehicle installation still requires the protected power-input stage and
automotive transient protection on the sensor input.

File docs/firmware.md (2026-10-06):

# Firmware build and source guide

[Documentation index](README.md) · [CAN protocol](can-protocol.md)

The firmware targets the STM32G0B1RET6 on the NUCLEO-G0B1RE. It uses ST's HAL,
a polling main loop, ADC1, and FDCAN1 operating in Classical CAN mode.

## Clone and dependencies

```powershell
git clone https://github.com/nayman898/van-canbus.git
cd van-canbus
git submodule update --init --depth 1 third_party/STM32CubeG0
git -C third_party/STM32CubeG0 submodule update --init --depth 1 Drivers/STM32G0xx_HAL_Driver Drivers/CMSIS/Device/ST/STM32G0xx
```

The repository pins STM32CubeG0 as a submodule. Initialize the two nested
driver modules shown above rather than downloading every example dependency.
GitHub source ZIPs do not include the initialized submodule contents.

## Build

The project is set up for STM32CubeIDE for VS Code. Open the repository, select
the `Debug` CMake preset, and build using the IDE's Arm toolchain environment.

For a command-line build, provide Git, CMake **3.21 or newer** (for the version-3
preset file; see [CMake's version table](https://cmake.org/cmake/help/latest/manual/cmake-presets.7.html#versions)),
Ninja, and the Arm GNU tools on `PATH`: `arm-none-eabi-gcc`,
`arm-none-eabi-g++`, and `arm-none-eabi-objcopy`.

```powershell
cmake --preset Debug
cmake --build --preset Debug
```

For an optimized build, use `Release` in both commands. The presets write to
separate `build/Debug` and `build/Release` directories.

| Debug output | Purpose |
| --- | --- |
| `build/Debug/van-canbus.elf` | Firmware with symbols for programming/debugging |
| `build/Debug/van-canbus.hex` | Intel HEX image with addresses |
| `build/Debug/van-canbus.bin` | Raw binary image |
| `build/Debug/van-canbus.map` | Linker memory map |

The HEX and BIN files are generated automatically after a successful link.
If configuring outside the IDE, use a shell with the toolchain available;
the repository does not bundle the compiler, CMake, or Ninja.

## Program the board

Connect the Nucleo through its onboard ST-Link USB connection. Use the IDE's
ST-Link programming/debug workflow for the `van-canbus.elf` artifact, or open
the generated HEX in STM32CubeProgrammer and program through ST-Link/SWD.
Start/reset the target after programming, then verify reception using the
[bench guide](bench-setup.md). Building an image alone does not program it.

## What the code does

At startup the firmware configures its clock, PA5 status LED, ADC1, and FDCAN1,
including ADC calibration before starting CAN. The main loop schedules the
heartbeat every 500 ms and both coolant channels every 250 ms: pre-radiator
on A0/PA0 and post-radiator on A1/PA1.

Each channel selection replaces rank 1 in the configurable ADC sequencer.
The first conversion after switching channels is discarded for settling.
Each coolant reading then averages 32 ADC conversions, checks fault thresholds,
and converts thermistor resistance to temperature with a Steinhart-Hart fit.
Failed ADC reads produce a fault payload instead of a valid temperature.

The three sequence counters advance independently when frames are successfully
queued. PA5 toggles on a queued heartbeat, not on confirmation that the laptop
received it. The CAN controller uses automatic retransmission. Incoming frames
are rejected by the configured global filter; there is no command handler.

| File | Responsibility |
| --- | --- |
| [Src/main.c](../Src/main.c) | Peripheral configuration, scheduling, ADC averaging, CAN transmission |
| [Src/stm32g0xx_hal_msp.c](../Src/stm32g0xx_hal_msp.c) | Peripheral clocks and PA0/PA1/PA11/PA12 pin setup |
| [Inc/can_protocol.h](../Inc/can_protocol.h) | Message IDs, periods, protocol constants |
| [Src/can_protocol.c](../Src/can_protocol.c) | Byte-level payload encoding |
| [Inc/tx3_sensor.h](../Inc/tx3_sensor.h) | Pull-up value, thresholds, status flags |
| [Src/tx3_sensor.c](../Src/tx3_sensor.c) | Thermistor conversion and range/fault handling |
| [CMakeLists.txt](../CMakeLists.txt) | Target sources, HAL dependencies, HEX/BIN generation |

## Changing the prototype

- **Different measured pull-up:** update `TX3_PULLUP_OHMS` and check against an
  independent temperature measurement.
- **Different CAN bitrate:** change the actual FDCAN timing in `FDCAN1_Init`
  and the host tool's `--bitrate`. Editing `CAN_BUS_BITRATE` alone does not
  reconfigure the peripheral; its timing fields are currently set explicitly.
- **Second TX3 sensor:** duplicate the first divider on A1/PA1. Both use
  `TX3_PULLUP_OHMS`; do not use a different pull-up value on channel 2.
  See the [bench wiring and acceptance test](bench-setup.md#second-coolant-channel).

## Checks

With the Python dependencies installed, run the existing host decoder tests:

```powershell
.\.venv\Scripts\python -m unittest discover -s tests -v
```

These tests exercise heartbeat/coolant parsing, malformed payload lengths, and
fault presentation. They do not validate MCU timing, physical wiring, sensor
calibration, or vehicle-input protection. Those need the documented bench and
hardware checks.

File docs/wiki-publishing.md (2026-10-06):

# Publishing the GitHub wiki

The [public wiki](https://github.com/nayman898/van-canbus/wiki) is generated from
the build documentation in this repository. Make content changes here first,
then export and publish the wiki. Direct edits to generated wiki pages will
be replaced by the next export.

Successful pushes to `main` now publish automatically through the
[verification and build workflow](automation.md). It uses the built-in token
with write permission limited to the publishing job, or an optional `WIKI_TOKEN`
secret. Pull requests only generate a downloadable preview. The manual steps
below remain available.

## Preview locally

From the repository root, using Python 3.10 or newer:

```powershell
py -3 tools/export_wiki.py --output .cache/wiki-preview
```

This generates twelve pages, `_Sidebar.md`, and `_Footer.md`. Links between guides
become wiki links; source-code links point back to the main repository.
Fenced code examples remain unchanged. The script does not commit or push.

## Publish

The wiki must already have an initial page saved on GitHub. Clone its separate
Git repository beside the project (only needed once):

```powershell
git clone https://github.com/nayman898/van-canbus.wiki.git ../van-canbus.wiki
```

Commit and publish the source documentation in the main repository first, so
the wiki's source links refer to the published build notes. Then, with a clean
wiki checkout:

```powershell
git -C ../van-canbus.wiki pull --ff-only
py -3 tools/export_wiki.py --output ../van-canbus.wiki
git -C ../van-canbus.wiki diff --check
git -C ../van-canbus.wiki status --short
git -C ../van-canbus.wiki diff
```

Review new files as well as the diff. Stage only the generated files:

```powershell
git -C ../van-canbus.wiki add Home.md Build-Guide.md Build-Progress.md Hardware.md Bench-Setup.md Harness-and-Power.md Firmware.md CAN-Protocol.md Laptop-Tools.md Android-App.md Automation.md Wiki-Publishing.md _Sidebar.md _Footer.md
git -C ../van-canbus.wiki commit -m "Update build documentation"
git -C ../van-canbus.wiki push origin HEAD
```

The export replaces the named generated pages and navigation files. It does
not delete unrelated wiki pages. Use the wiki's existing default branch; do
not assume it has the same branch name as the source repository.

To add another generated page, extend `PAGES` in
[export_wiki.py](../tools/export_wiki.py) and the staging command above. The
sidebar is generated from that mapping. The exporter supports the inline
Markdown links and fenced blocks used by the current guides; extend its
handling before introducing other link formats.

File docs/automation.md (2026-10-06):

# Automated checks and builds

[Documentation index](README.md) · [Android dashboard](../android-app/README.md)

The [Verify, build, and publish wiki workflow](../.github/workflows/verify-build.yml)
runs on pushes to `main`, pull requests targeting `main`, and **Actions → Verify,
build, and publish wiki → Run workflow**. Pull requests run checks and builds;
only successful `main` runs in the original repository can publish the wiki.

## What runs

| Job | Checks and output |
| --- | --- |
| Host tools and documentation | Python decoder/dashboard/wiki tests, Python bug checks, dashboard JavaScript syntax and dual-temperature UI tests, Actions validation, generated wiki with local-link checks |
| Firmware (Debug / Release) | C encoder golden vectors; compile/link the STM32 firmware in both configurations; memory use and checksums |
| Android checks and APK | Gradle wrapper validation, Java decoder golden vectors, Android lint, Gradle unit tests, debug APK and reports |
| Publish generated wiki | Runs after every required job passes; updates only mapped pages and navigation; skips unchanged docs and stale main commits |

These are software checks, not a hardware certification. USB enumeration,
actual CAN timing/ACKs, sensor calibration, power protection, and display layout
still need bench/device tests. CI never flashes the Nucleo or sends CAN frames.

## Android SDK setup and Dependabot PRs

The Android job explicitly runs SHA-pinned `android-actions/setup-android`
before `sdkmanager`. This installs/configures command-line tools and places
`sdkmanager` on PATH rather than assuming the hosted runner exposes it.
The following step installs `platforms;android-36` and `build-tools;35.0.0`.
SDK setup runs for PRs too and does not require signing or wiki secrets.

If an older run fails with **`sdkmanager: command not found`**, ensure the
branch includes the SDK setup fix. After merging the fix into `main`, update
or rebase the Dependabot PR branch and run its checks again. Merely rerunning
the old failing commit does not add the missing workflow step. The fix was
validated locally; a hosted success must be checked in Actions.

## Download a build

Open the repository's **Actions** tab, select a completed run for the desired
commit, and scroll to **Artifacts**. Download and unzip:

- `android-debug-<commit>`: installable APK and SHA-256 checksum.
- `firmware-Debug-<commit>` / `firmware-Release-<commit>`: ELF, HEX, BIN,
  linker memory map, and checksums.
- `android-reports-<commit>`: lint and any Gradle test reports, including on failure.
- `wiki-preview-<commit>`: generated Markdown pages for review.

Artifacts expire after 14 days to limit storage use. Save builds you want to
keep. Overlapping runs for the same branch cancel older runs. Build dependencies
are cached, and Actions are pinned to commit hashes.

## Android signing for repeated phone updates

The APK is a debug/test build, not a Play Store release. A fresh hosted runner
normally generates a fresh debug signing key. Android cannot install it over
an app signed by a different key; uninstalling the old app also removes its
private logs, so export logs first.

For consistent signatures on builds from `main`, optionally add the repository
Actions secret `ANDROID_DEBUG_KEYSTORE_BASE64`, containing a base64-encoded
**debug keystore**. Use the same debug keystore as the local build if you want
to update that installation. Keep its standard alias `androiddebugkey` and
standard debug passwords `android`. Do not use a production signing key.
The secret is used only on `main`, never for pull requests. Local build tools
may place the key in the user's `.android` directory or a configured Android
user directory; confirm the path with Android Studio's signing report.

The workflow does not create or upload a signing key for you. Store secrets
under **Settings → Secrets and variables → Actions**, never in tracked files.

## Wiki publishing

The wiki is generated from the repository documentation, including the Android
guide and this page. It does not invent or rewrite technical instructions.
The publishing job uses the same-repository `GITHUB_TOKEN` with `contents: write`.
If repository policy requires a different credential, add an Actions secret
named `WIKI_TOKEN` with access to this repository's wiki; it takes precedence.

The wiki must be enabled and have at least one page saved on GitHub before its
Git backend can be cloned. Both were present when this workflow was prepared.
Publishing failures remain visible as failed jobs; the downloadable wiki preview
is still available. See [Wiki publishing](wiki-publishing.md) for manual export.

## Routine maintenance

[Dependabot configuration](../.github/dependabot.yml) proposes grouped weekly
updates to Actions, Python dependencies, and the Android Gradle plugin. It opens
pull requests; it does not merge them. Gradle wrapper/toolchain upgrades may
need to be coordinated with Android SDK versions. The workflow-linter version
and checksum in [check-workflows.sh](../tools/ci/check-workflows.sh) are maintained
manually.

[EditorConfig](../.editorconfig) and [Git attributes](../.gitattributes) provide
consistent whitespace and Windows/Linux line endings for future edits. Checks
report likely errors without automatically reformatting or committing code.
Android lint reports warnings, but errors fail the build. Physical tests remain
necessary before trusting a new build in the van.

## Run equivalent checks locally

```sh
python -m pip install -r requirements.txt -r requirements-ci.txt
python -m ruff check --select E9,F63,F7,F82 tools tests
python -m unittest discover -s tests -v
node --check tools/dashboard/app.js
node tests/test_dashboard.js
python tools/export_wiki.py --output .cache/wiki-preview
cmake --preset Debug
cmake --build --preset Debug
cmake --preset Release
cmake --build --preset Release
```

In `android-app`, use JDK 21 and run `gradlew.bat :app:lintDebug
:app:testDebugUnitTest :app:assembleDebug` on Windows, or the same tasks with
`bash gradlew` on Linux. The firmware commands require the Arm toolchain and
initialized STM32 submodules described in [Firmware](firmware.md).

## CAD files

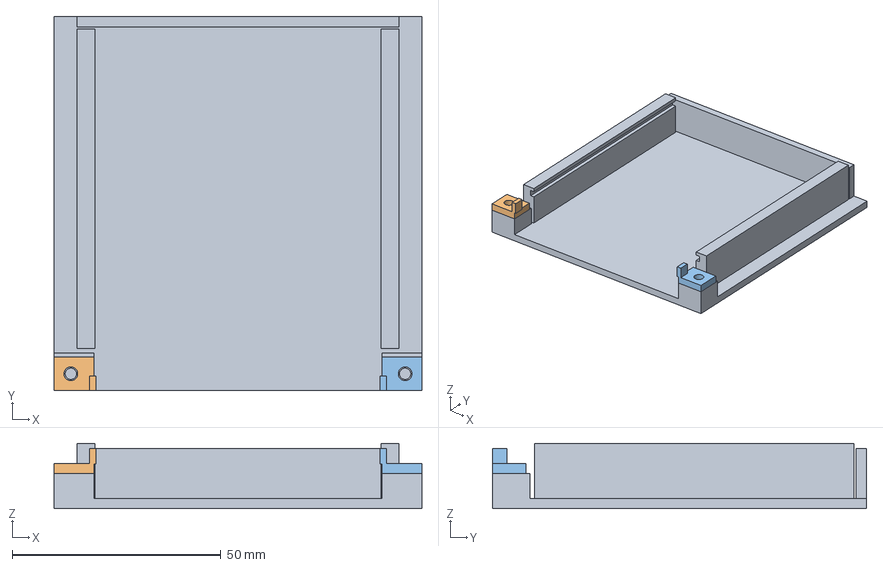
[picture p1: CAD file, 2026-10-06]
hardware/protective-plates/step/pilot_2.70mm/nucleo_assembled.step
88.0 x 89.5 x 15.6 mm
Tray
Stop_left
Stop_right

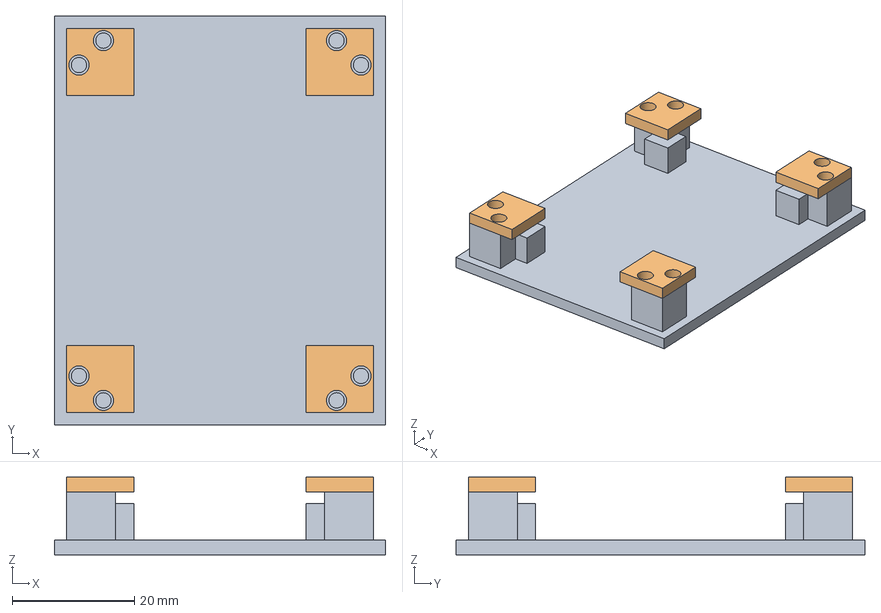
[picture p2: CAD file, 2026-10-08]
hardware/protective-plates/eplzon-corners/assembled.step
54.1 x 66.8 x 12.7 mm

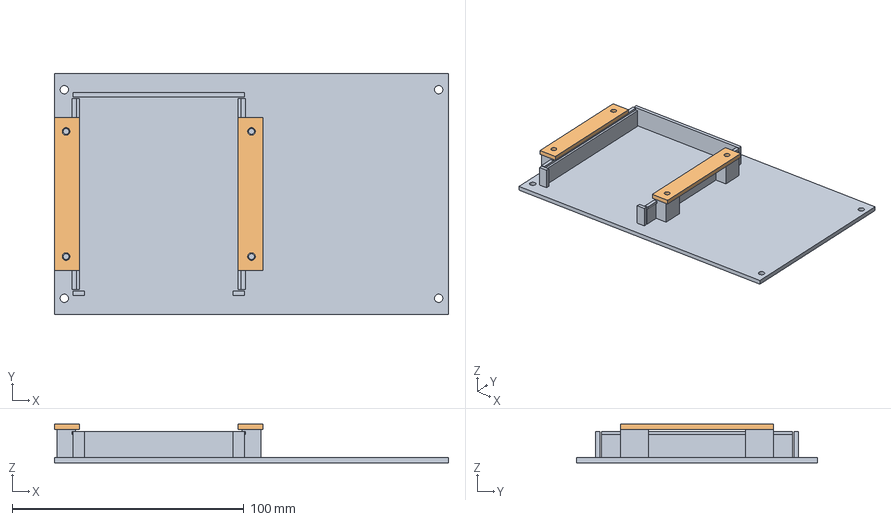
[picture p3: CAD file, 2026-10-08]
hardware/protective-plates/hammond-v2/assembled.step
170.0 x 104.0 x 16.8 mm
Carrier
Left_retainer
Right_retainer

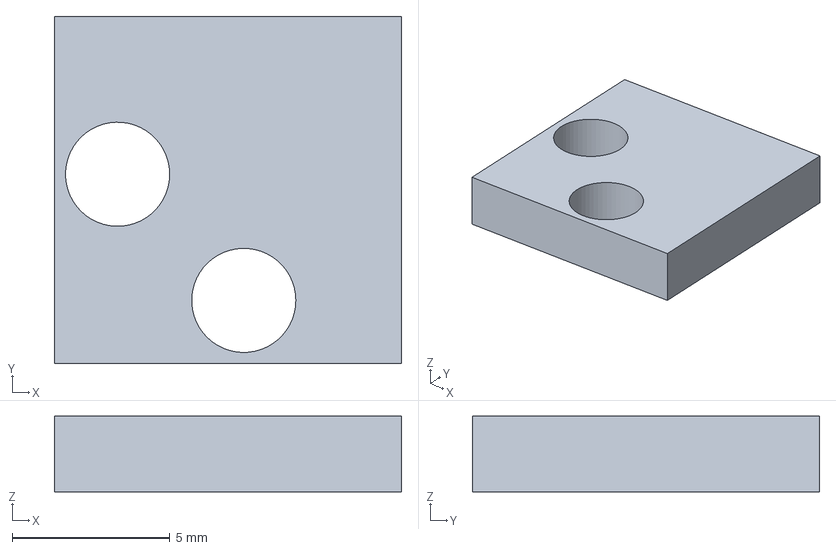
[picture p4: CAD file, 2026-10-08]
hardware/protective-plates/eplzon-corners/corner_clip_print_four.step
11.0 x 11.0 x 2.40 mm

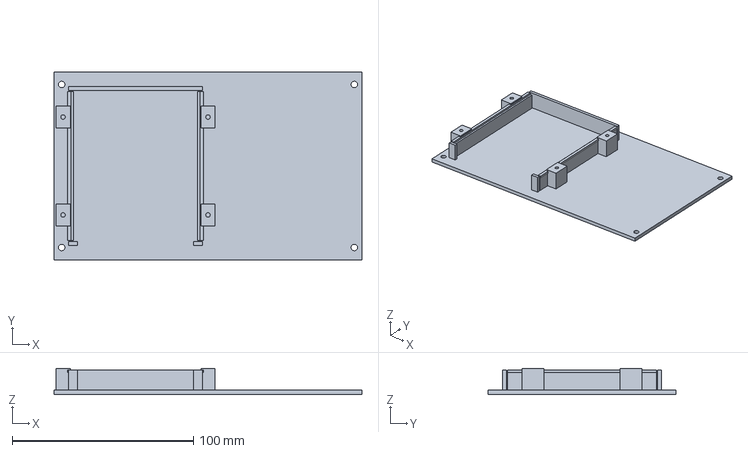
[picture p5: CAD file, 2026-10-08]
hardware/protective-plates/hammond-v2/carrier.step
170.0 x 104.0 x 14.4 mm

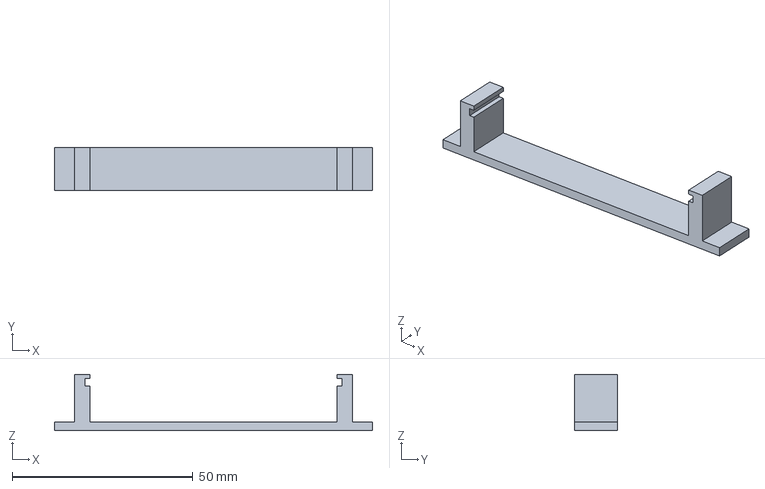
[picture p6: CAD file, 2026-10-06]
hardware/protective-plates/step/pilot_2.50mm/nucleo_rail_fit_test.step
88.0 x 12.0 x 15.6 mm

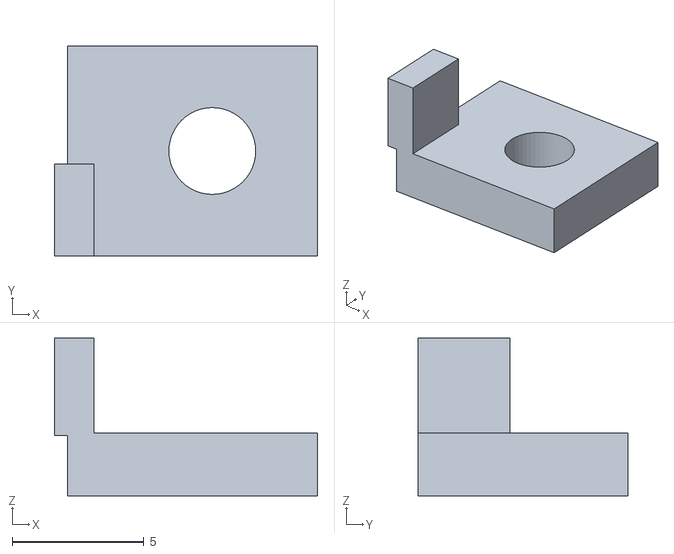
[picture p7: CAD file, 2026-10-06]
hardware/protective-plates/stl/nucleo_stop_right.stl
10.0 x 8.00 x 6.00

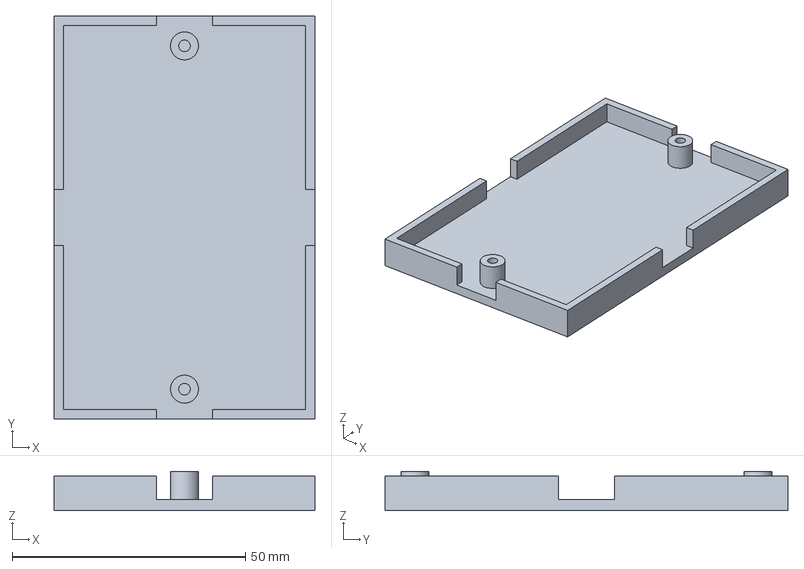
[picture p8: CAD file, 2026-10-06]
hardware/protective-plates/step/pilot_2.50mm/permaproto_half_1609_tray.step
56.0 x 86.5 x 8.40 mm

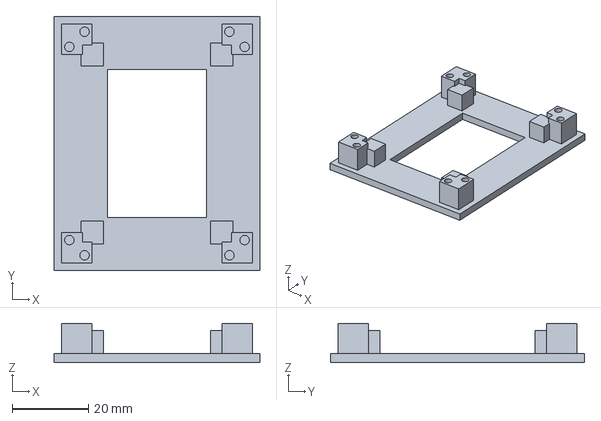
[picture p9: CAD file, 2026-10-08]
hardware/protective-plates/eplzon-corners/fit_test_frame.step
54.1 x 66.8 x 10.3 mm

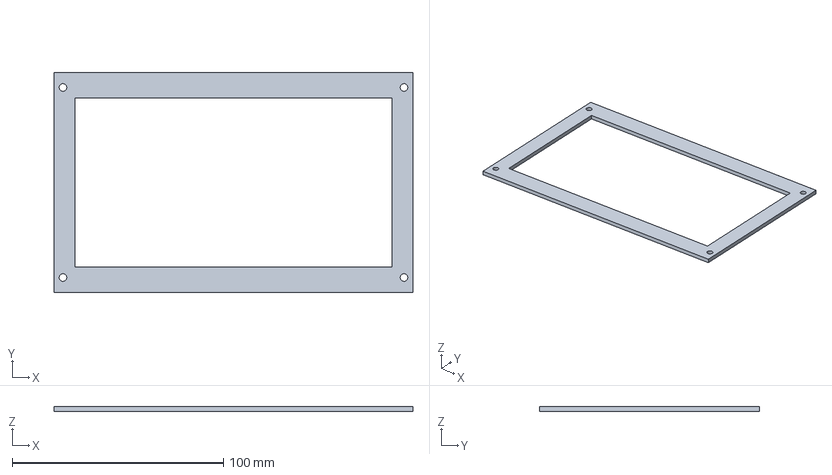
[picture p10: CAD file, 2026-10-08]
hardware/protective-plates/hammond-v2/case_mount_fit_test.step
170.0 x 104.0 x 2.40 mm

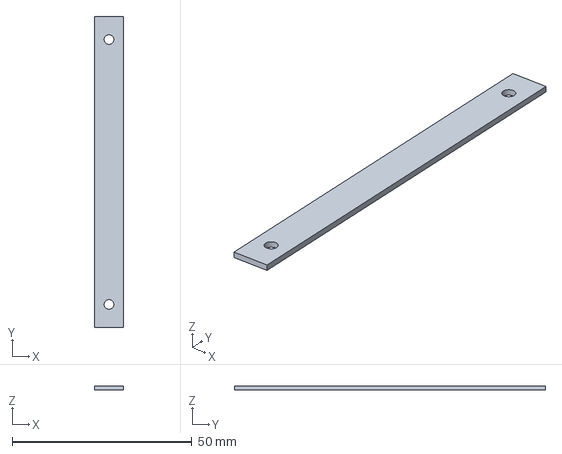
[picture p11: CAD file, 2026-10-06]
hardware/protective-plates/step/pilot_2.70mm/permaproto_half_1609_fit_test.step
8.00 x 86.5 x 1.20 mm

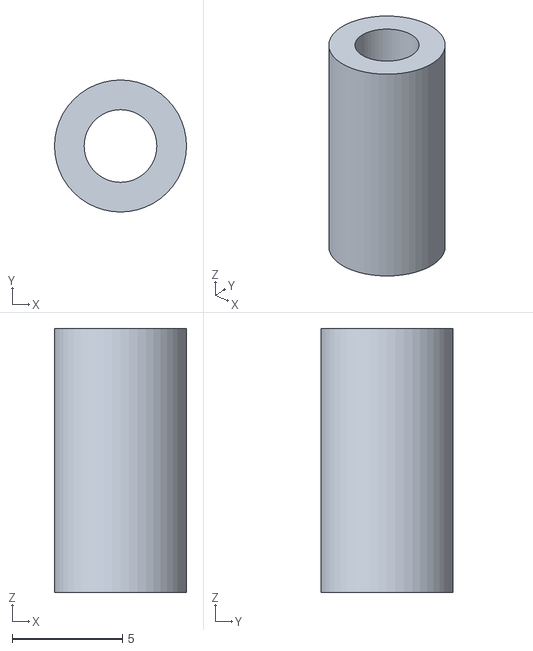
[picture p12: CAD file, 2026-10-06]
hardware/protective-plates/stl/m3_spacer_12mm.stl
6.00 x 6.00 x 12.0

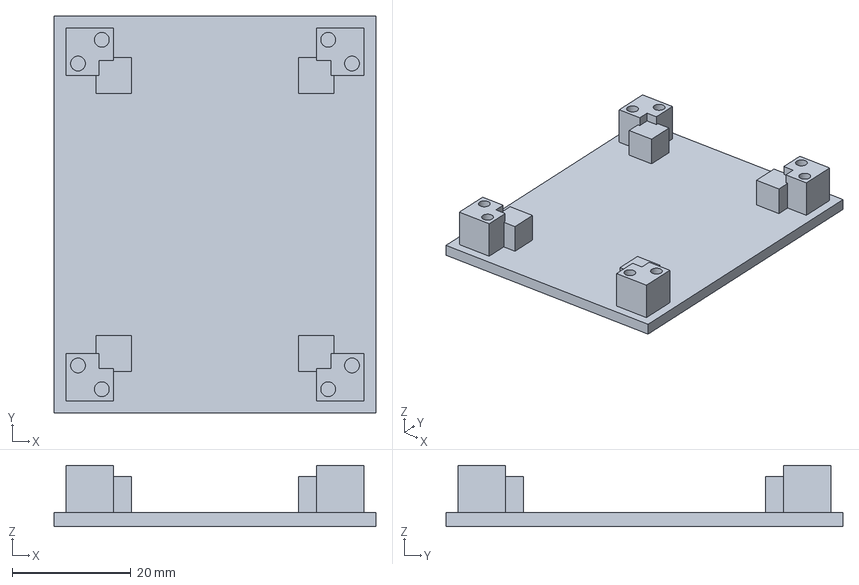
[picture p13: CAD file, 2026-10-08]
hardware/protective-plates/eplzon-corners/tray.step
54.1 x 66.8 x 10.3 mm

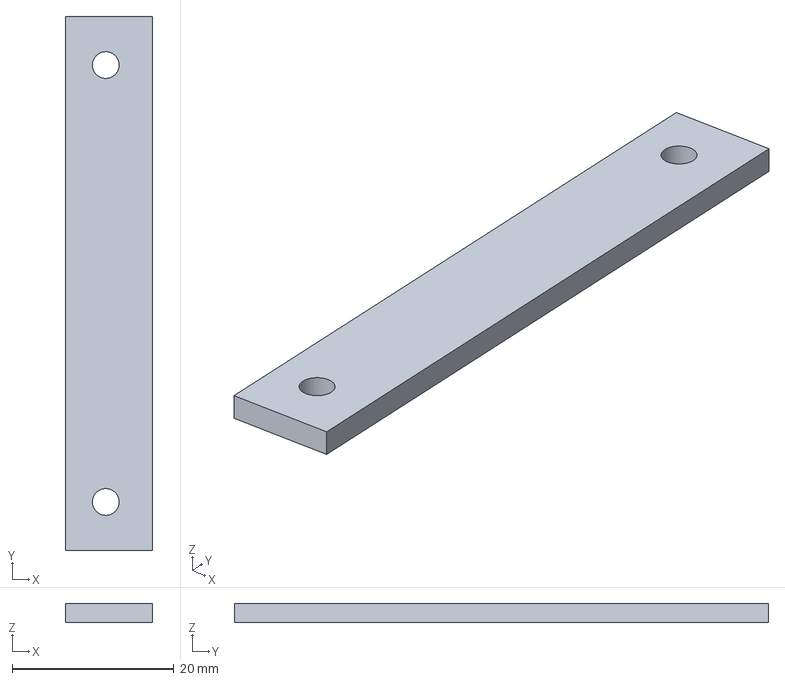
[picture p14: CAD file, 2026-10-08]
hardware/protective-plates/hammond-v2/retainer_print_two.step
10.8 x 66.0 x 2.40 mm

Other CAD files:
hardware/protective-plates/step/pilot_2.50mm/nucleo_assembled.step
hardware/protective-plates/step/pilot_2.70mm/nucleo_stop_right.step
hardware/protective-plates/stl/nucleo_stop_left.stl
hardware/protective-plates/step/pilot_2.50mm/nucleo_stop_right.step
hardware/protective-plates/eplzon-corners/corner_clip_print_four.stl
hardware/protective-plates/eplzon-corners/fit_test_frame.stl
hardware/protective-plates/eplzon-corners/tray.stl
hardware/protective-plates/hammond-v2/carrier.stl
hardware/protective-plates/hammond-v2/case_mount_fit_test.stl
hardware/protective-plates/hammond-v2/retainer_print_two.stl
hardware/protective-plates/step/pilot_2.50mm/eplzon_38x51_fit_test.step
hardware/protective-plates/step/pilot_2.50mm/eplzon_38x51_tray.step
hardware/protective-plates/step/pilot_2.50mm/nucleo_edge_tray_8mm_pins.step
hardware/protective-plates/step/pilot_2.50mm/nucleo_stop_left.step
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

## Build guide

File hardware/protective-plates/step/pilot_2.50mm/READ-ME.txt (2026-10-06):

Van CAN bottom guards - millimetres
Pilot diameter: 2.50 mm; clearance holes stay 3.3 mm.
STEP contains analytic solids, not meshes; it does not contain Fusion/Onshape feature history.
Import an individual STEP to edit one part, or nucleo_assembled.step for the three-part assembly.
Use direct face edits or add new sketches/features. Source scripts and JSON are included for regeneration.
Install requirements-step.txt in Python 3.12+, then run export_step.py.
For 2.5 mm pilots: python export_step.py --pilot-diameter 2.5
Existing STL files are not changed by STEP export. Export revised STLs from your CAD application.
First-fit bench prototypes, not physically verified or sealed automotive enclosures.
Read docs/hardware.md in the repository for printing, clearances and assembly precautions.

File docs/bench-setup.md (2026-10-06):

# Build the USB-powered bench network

[Documentation index](README.md) · [Hardware](hardware.md) · [Laptop tools](../tools/README.md)

This guide reproduces the current one-sensor bench setup. Keep vehicle power
disconnected throughout. Prepare the [firmware](firmware.md) and
[Python environment](../tools/README.md#install-on-windows) before bring-up.

## 1. Wire the Nucleo and CAN Pal

With power removed, connect:

| Nucleo | CAN Pal |
| --- | --- |
| 3V3 | Vcc |
| GND | GND |
| GND | SLNT |
| PA12 / FDCAN1_TX | TX |
| PA11 / FDCAN1_RX | RX |

Use the board labels and the [MB1360 manual](hardware.md#manufacturer-references)
to locate the pins. These are MCU port names, not connector cavity numbers.

## 2. Wire the CAN bus

| CAN Pal | U2C normal CAN OUT connection |
| --- | --- |
| H | H |
| L | L |
| GND | GND |

Keep H and L together as a twisted pair and carry the reference ground with
them. Leave U2C **V+ disconnected**. Enable one 120-ohm terminator at the CAN
Pal end and one at the U2C end using its `120R` jumper.

With both USB cables and all other power disconnected, measure H to L. The
two enabled terminations should measure approximately **60 ohms**. A reading
near 120 ohms suggests one termination is missing; a reading near zero calls
for a short-circuit check before powering up.

## 3. Add the coolant input

Sensor 1 is **pre-radiator** (engine outlet). Sensor 2 is **post-radiator**
(radiator outlet). The following circuit applies independently to each.

Build the [TX3 divider](hardware.md#first-coolant-input), with its output through
1 kohm to A0/PA0. Return the sensor's other wire to the Nucleo ground.

### Second coolant channel

Power off before changing wiring. Duplicate the first TX3 input; do not share
the signal junction or pull-up between sensors:

```text
3V3 ── 2.47 kohm ──┬── TX3 #2 ── sensor return / GND
                   │
                   └── 1 kohm ── A1 / PA1
                                   │
                                 100 nF
                                   │
                                  GND
```

The pull-up may be 2 kohm + 470 ohm in series. The separate 1-kohm resistor
is in the ADC signal lead, not the sensor return. Use the same input protection
as channel 1. Never apply 5 V or 12 V to either ADC input.
A1 is PA1/ADC1_IN1 per [ST UM2324, Arduino connector table](https://www.st.com/resource/en/user_manual/dm00452640.pdf).

1. Flash the two-channel firmware and install the updated Android APK (or
   restart the browser dashboard backend and reload the page).
2. Expect `0x110` sensor ID 1 and `0x111` sensor ID 2, each about four frames
   per second, plus two heartbeats per second (about ten frames/s total).
3. Verify both readings against room temperature, then warm only sensor 2:
   only **post-radiator** should change. Repeat for sensor 1.
4. Disconnect sensor 2 with its pull-up still connected. Post-radiator should
   show OPEN; pre-radiator must continue updating. Reconnect and verify recovery.
5. Stop the node: both temperatures must become stale, not remain displayed
   as live values. Android raw CSV logs include both IDs without extra setup.

Two-channel firmware was flashed and verified during the October 5–6, 2026
session. Phone operation was confirmed and both valid channels were received
on the PC after restarting its backend. Complete the individual warming,
fault-recovery, and calibration checks above before relying on the installation.

The first channel is the thermostat-outlet channel in the protocol. It can
be tested with the sensor on the bench before mechanical installation.
Both ADC channels are implemented; mechanical installation is a separate step.

If using enclosure connectors, use one complete allocation from the
[harness plan](engine-node-harness.md). The old temporary combined 12-pin C0
and the proposed sensor-only 12-pin C2 have different assignments and are not
interchangeable.

## 4. Power and start the monitor

1. Check continuity, polarity, and for unintended shorts while unpowered.
2. Use the Nucleo's USB power configuration; disconnect external E5V/vehicle
   feeds. If the jumpers were changed for a converter test, restore the USB
   configuration using the board manual first.
3. Connect the Nucleo's ST-Link USB data cable and program the built firmware.
4. Connect the U2C to the laptop by USB.
5. Start `start_dashboard.bat`, or use the commands in the
   [laptop-tools guide](../tools/README.md).

Run one application against the U2C at a time. Stop the dashboard before using
the terminal monitor against the same adapter.

## 5. Check the result

| Observation | Expected behavior |
| --- | --- |
| Dashboard connection | Changes to `CAN live` when traffic arrives |
| Heartbeat | Node uptime increases; sequence changes about twice per second |
| Coolant | A plausible bench temperature, updated about four times per second |
| ADC | Count between the configured short/open thresholds for a connected sensor |
| Frame count | About ten frames per second: four per coolant channel plus two heartbeats |
| Nucleo PA5 LED | Toggles when a heartbeat is queued; this alone does not prove bus reception |

The original bench notes recorded 1.69 V with a sensor near 2.60 kohm.
That is an example measurement, not a fixed voltage every sensor should show.
Temperature and actual pull-up resistance affect the reading.

To check open-circuit reporting, power down, disconnect one thermistor wire,
and power up again. The dashboard should show an open-circuit fault. Power down
again before restoring the connection.

## Troubleshooting

| Symptom | Check |
| --- | --- |
| U2C disconnected | USB data cable, adapter firmware/backend, and whether another app owns the adapter |
| Adapter connected, no frames | Node power/firmware, H/L assignment, common ground, termination, and 500 kbit/s on both ends |
| Open-circuit fault | Sensor connection and dedicated return; ADC count at or above 4050 |
| Short-circuit fault | Signal-to-ground short or divider wiring; ADC count at or below 16 |
| Plausible but wrong temperature | Actual pull-up resistance and whether the sensor matches the assumed calibration |
| Temperature stops changing | Connection status and last-frame age; the dashboard retains its last reading |

For software errors, see [tool troubleshooting](../tools/README.md#troubleshooting).
For vehicle-power work, continue with the [harness plan](engine-node-harness.md)
only after the bench setup is working.

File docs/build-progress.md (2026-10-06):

# Build progress

[Documentation index](README.md) · [Project home](../README.md)

This is a milestone record for readers following the build. It describes the
working prototype and the plans present in this repository, rather than a
finished vehicle installation.

## 1. Get two CAN endpoints talking — working on the bench

The engine node pairs a NUCLEO-G0B1RE with an Adafruit CAN Pal. A BTT U2C V2.1
connects the bus to the laptop. The first useful message is a heartbeat with
node identity, sequence, and uptime, making it possible to see that the node
is running and messages are arriving.

The link uses Classical CAN at 500 kbit/s. See [bench setup](bench-setup.md)
for the wiring and termination checks.

## 2. Read the first coolant sensor — working on the bench

A TX3 thermistor and nominal 2.47-kohm pull-up feed A0/PA0 through a 1-kohm
series resistor. Firmware averages the ADC samples, calculates temperature,
and transmits both the temperature and raw ADC reading. Open/short detection
makes a disconnected sensor distinguishable from a real temperature.

The first recorded bench check was 1.69 V with a sensor near 2.60 kohm. That
confirmed the initial circuit's behavior at that test point; it was not a full
temperature calibration or a vehicle-environment test. The intended location
for this channel is the thermostat outlet.

See [hardware](hardware.md) for the circuit and current calibration assumptions.

## 3. Make the data easy to see — working on the laptop

The terminal decoder grew into a local browser dashboard showing coolant,
sensor voltage, faults, node uptime, and connection state. The backend retries
when the USB CAN adapter is unavailable. It currently displays live data;
built-in persistent recording and playback are future work.

See [laptop tools](../tools/README.md) for setup and behavior.

## 4. Move toward an enclosure and harness — in progress

The intended split is a 6-pin power/CAN plug and a 12-pin sensor plug. Both
sizes are available for the build. Keeping these separate leaves room for
additional sensors and lets the sensor harness be serviced independently.

The older combined 12-pin arrangement is retained in the
[harness plan](engine-node-harness.md) as a temporary reference. Its pinout is
different from the sensor-only connector. The final housing part numbers,
orientation, contact sizes, cable exits, and mounting tray are still open.

## 5. Prepare vehicle power — parts selected

The purchased input-stage parts and staged bench procedure are recorded in the
[power section](engine-node-harness.md#selected-protected-vehicle-input-stage).
The intention is a fused and protected input ahead of the 5 V converter.
The repository does not yet document completed automotive transient or
load-dump validation, and a clean 12 V bench test would not establish that.

## 6. Two coolant channels and phone dashboard — bench operation confirmed

### Evening session: October 5–6, 2026 (America/New_York)

- Added the second TX3 end-to-end: ADC acquisition, CAN encoding, laptop
  decoder/dashboard, and native Android dashboard.
- Sensor 1 is **pre-radiator**, A0/PA0, CAN `0x110`, sensor ID 1. Sensor 2
  is **post-radiator**, A1/PA1, CAN `0x111`, sensor ID 2. Both use separate
  nominal 2.47-kohm pull-ups and the same TX3 conversion.
- Each channel sends about four frames per second with independent sequence
  and fault state. Together with heartbeat, normal traffic is about ten frames/s.
- Both dashboards now show independent readings and suppress temperatures
  when their channel is stale (1.5 seconds), invalid, or disconnected.
  Android stacks the cards on phones and places them side-by-side in wide
  landscape; its existing raw CSV logger records both IDs.
- Built Debug/Release firmware and the Android APK. C encoder checks, Java
  decoder checks, browser UI checks, and 22 Python tests passed. Android lint
  passed with three warnings and no errors.
- Programmed the connected NUCLEO-G0B1RE, verified flash contents, and reset
  it to run. The user confirmed successful operation and phone reception.
- Restarted the PC's old dashboard backend, which was still running the
  previous single-channel code with stale data. The new backend received
  both valid channels: 65.3 °F pre-radiator and approximately 90.0 °F
  post-radiator in that bench snapshot. These are test readings, not evidence
  of radiator performance or calibrated accuracy.

See [second-channel bench wiring](bench-setup.md#second-coolant-channel) and
the [CAN contract](can-protocol.md). Independent warming/disconnection checks,
calibration, and installation checks remain separate from confirmed reception.

## 7. Automated verification and build maintenance

The repository workflow checks host tools/docs, builds both firmware variants,
builds/lints the Android APK, and generates the wiki. Pull requests do not
publish the wiki; successful `main` runs can. Two-temperature browser tests
are included in the workflow.

A Dependabot PR exposed `sdkmanager: command not found`. The workflow now
explicitly initializes Android command-line tools with a SHA-pinned setup
action before installing SDK packages. Local workflow validation passed;
a successful hosted rerun of that fix has not yet been confirmed here.
See [automation](automation.md) for artifacts and troubleshooting.

## Next work

- Confirm connector part numbers/orientation and finalize the two-plug drawing.
- Assemble and measure the protected power stage before vehicle-power use.
- Add automotive transient protection to the sensor input.
- Verify channel identity by warming one sensor at a time, check fault recovery,
  and finalize the lower-radiator-hose sensor installation.
- Measure the GlowShift pressure interfaces before designing inputs that share
  those signals with the existing gauges.
- Finish enclosure support, strain relief, sealing, and the mounting tray.
- Exercise Android CSV logging with both sensors; laptop persistent recording
  and playback remain future work.

Add installation photos and enclosure drawings as the physical build progresses;
bench operation does not establish vehicle-environment reliability.

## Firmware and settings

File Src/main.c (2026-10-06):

#include "main.h"

#include "can_protocol.h"
#include "tx3_sensor.h"

FDCAN_HandleTypeDef hfdcan1;
ADC_HandleTypeDef hadc1;

#define ADC_AVERAGE_SAMPLE_COUNT 32U
#define ADC_CONVERSION_TIMEOUT_MS 10U

static void SystemClock_Config(void);
static void GPIO_Init(void);
static void ADC1_Init(void);
static void FDCAN1_Init(void);
static void FDCAN1_Start(void);
static bool ADC1_ReadAverage(uint32_t adc_channel, uint16_t *adc_raw);
static bool CAN_TrySend(uint32_t identifier, const uint8_t payload[8]);
static bool Heartbeat_TrySend(uint8_t sequence);
static bool CoolantTemperature_TrySend(uint8_t sensor_id, uint8_t sequence);

int main(void)
{
    uint8_t sequence = 0U;
    uint8_t coolant_sequence[2] = {0U, 0U};
    uint32_t next_heartbeat_ms;
    uint32_t next_coolant_ms;

    HAL_Init();
    SystemClock_Config();
    GPIO_Init();
    ADC1_Init();
    if (HAL_ADCEx_Calibration_Start(&hadc1) != HAL_OK) {
        Error_Handler();
    }
    FDCAN1_Init();
    FDCAN1_Start();

    next_heartbeat_ms = HAL_GetTick();
    next_coolant_ms = next_heartbeat_ms;

    for (;;) {
        const uint32_t now_ms = HAL_GetTick();

        if ((int32_t)(now_ms - next_heartbeat_ms) >= 0) {
            if (Heartbeat_TrySend(sequence)) {
                sequence++;
                HAL_GPIO_TogglePin(STATUS_LED_GPIO_Port, STATUS_LED_Pin);
            }
            next_heartbeat_ms += CAN_HEARTBEAT_PERIOD_MS;
        }

        if ((int32_t)(now_ms - next_coolant_ms) >= 0) {
            for (uint8_t sensor = 0U; sensor < 2U; ++sensor) {
                if (CoolantTemperature_TrySend(sensor + 1U, coolant_sequence[sensor])) {
                    coolant_sequence[sensor]++;
                }
            }
            next_coolant_ms += CAN_COOLANT_PERIOD_MS;
        }
    }
}

static void SystemClock_Config(void)
{
    RCC_OscInitTypeDef oscillator = {0};
    RCC_ClkInitTypeDef clocks = {0};

    if (HAL_PWREx_ControlVoltageScaling(PWR_REGULATOR_VOLTAGE_SCALE1) != HAL_OK) {
        Error_Handler();
    }

    oscillator.OscillatorType = RCC_OSCILLATORTYPE_HSI;
    oscillator.HSIState = RCC_HSI_ON;
    oscillator.HSIDiv = RCC_HSI_DIV1;
    oscillator.HSICalibrationValue = RCC_HSICALIBRATION_DEFAULT;
    oscillator.PLL.PLLState = RCC_PLL_ON;
    oscillator.PLL.PLLSource = RCC_PLLSOURCE_HSI;
    oscillator.PLL.PLLM = RCC_PLLM_DIV1;
    oscillator.PLL.PLLN = 8U;
    oscillator.PLL.PLLP = RCC_PLLP_DIV2;
    oscillator.PLL.PLLQ = RCC_PLLQ_DIV2;
    oscillator.PLL.PLLR = RCC_PLLR_DIV2;
    if (HAL_RCC_OscConfig(&oscillator) != HAL_OK) {
        Error_Handler();
    }

    clocks.ClockType = RCC_CLOCKTYPE_HCLK | RCC_CLOCKTYPE_SYSCLK | RCC_CLOCKTYPE_PCLK1;
    clocks.SYSCLKSource = RCC_SYSCLKSOURCE_PLLCLK;
    clocks.AHBCLKDivider = RCC_SYSCLK_DIV1;
    clocks.APB1CLKDivider = RCC_HCLK_DIV1;
    if (HAL_RCC_ClockConfig(&clocks, FLASH_LATENCY_2) != HAL_OK) {
        Error_Handler();
    }
}

static void GPIO_Init(void)
{
    GPIO_InitTypeDef gpio = {0};

    __HAL_RCC_GPIOA_CLK_ENABLE();

    HAL_GPIO_WritePin(STATUS_LED_GPIO_Port, STATUS_LED_Pin, GPIO_PIN_RESET);
    gpio.Pin = STATUS_LED_Pin;
    gpio.Mode = GPIO_MODE_OUTPUT_PP;
    gpio.Pull = GPIO_NOPULL;
    gpio.Speed = GPIO_SPEED_FREQ_LOW;
    HAL_GPIO_Init(STATUS_LED_GPIO_Port, &gpio);
}

static void ADC1_Init(void)
{
    ADC_ChannelConfTypeDef channel = {0};

    hadc1.Instance = ADC1;
    hadc1.Init.ClockPrescaler = ADC_CLOCK_SYNC_PCLK_DIV2;
    hadc1.Init.Resolution = ADC_RESOLUTION_12B;
    hadc1.Init.DataAlign = ADC_DATAALIGN_RIGHT;
    hadc1.Init.ScanConvMode = ADC_SCAN_DISABLE;
    hadc1.Init.EOCSelection = ADC_EOC_SINGLE_CONV;
    hadc1.Init.LowPowerAutoWait = DISABLE;
    hadc1.Init.LowPowerAutoPowerOff = DISABLE;
    hadc1.Init.ContinuousConvMode = DISABLE;
    hadc1.Init.NbrOfConversion = 1U;
    hadc1.Init.DiscontinuousConvMode = DISABLE;
    hadc1.Init.ExternalTrigConv = ADC_SOFTWARE_START;
    hadc1.Init.ExternalTrigConvEdge = ADC_EXTERNALTRIGCONVEDGE_NONE;
    hadc1.Init.DMAContinuousRequests = DISABLE;
    hadc1.Init.Overrun = ADC_OVR_DATA_OVERWRITTEN;
    hadc1.Init.SamplingTimeCommon1 = ADC_SAMPLETIME_160CYCLES_5;
    hadc1.Init.SamplingTimeCommon2 = ADC_SAMPLETIME_160CYCLES_5;
    hadc1.Init.OversamplingMode = DISABLE;
    hadc1.Init.TriggerFrequencyMode = ADC_TRIGGER_FREQ_LOW;
    if (HAL_ADC_Init(&hadc1) != HAL_OK) {
        Error_Handler();
    }

    channel.Channel = ADC_CHANNEL_0;
    channel.Rank = ADC_REGULAR_RANK_1;
    channel.SamplingTime = ADC_SAMPLINGTIME_COMMON_1;
    if (HAL_ADC_ConfigChannel(&hadc1, &channel) != HAL_OK) {
        Error_Handler();
    }
}

static void FDCAN1_Init(void)
{
    hfdcan1.Instance = FDCAN1;
    hfdcan1.Init.ClockDivider = FDCAN_CLOCK_DIV1;
    hfdcan1.Init.FrameFormat = FDCAN_FRAME_CLASSIC;
    hfdcan1.Init.Mode = FDCAN_MODE_NORMAL;
    hfdcan1.Init.AutoRetransmission = ENABLE;
    hfdcan1.Init.TransmitPause = DISABLE;
    hfdcan1.Init.ProtocolException = DISABLE;

    /* 64 MHz / 8 / (1 sync + 13 seg1 + 2 seg2) = 500 kbit/s. */
    hfdcan1.Init.NominalPrescaler = 8U;
    hfdcan1.Init.NominalSyncJumpWidth = 2U;
    hfdcan1.Init.NominalTimeSeg1 = 13U;
    hfdcan1.Init.NominalTimeSeg2 = 2U;

    /* Required by the peripheral even though CAN FD/BRS is disabled. */
    hfdcan1.Init.DataPrescaler = 8U;
    hfdcan1.Init.DataSyncJumpWidth = 1U;
    hfdcan1.Init.DataTimeSeg1 = 5U;
    hfdcan1.Init.DataTimeSeg2 = 2U;

    hfdcan1.Init.StdFiltersNbr = 0U;
    hfdcan1.Init.ExtFiltersNbr = 0U;
    hfdcan1.Init.TxFifoQueueMode = FDCAN_TX_FIFO_OPERATION;

    if (HAL_FDCAN_Init(&hfdcan1) != HAL_OK) {
        Error_Handler();
    }
}

static void FDCAN1_Start(void)
{
    if (HAL_FDCAN_ConfigGlobalFilter(&hfdcan1,
                                     FDCAN_REJECT,
                                     FDCAN_REJECT,
                                     FDCAN_REJECT_REMOTE,
                                     FDCAN_REJECT_REMOTE) != HAL_OK) {
        Error_Handler();
    }

    if (HAL_FDCAN_Start(&hfdcan1) != HAL_OK) {
        Error_Handler();
    }
}

static bool ADC1_ReadAverage(uint32_t adc_channel, uint16_t *adc_raw)
{
    uint32_t sample_sum = 0U;
    ADC_ChannelConfTypeDef channel = {0};

    if (adc_raw == NULL) {
        return false;
    }

    /* ADC_SCAN_DISABLE uses the configurable sequencer: replace rank 1. */
    channel.Channel = adc_channel;
    channel.Rank = ADC_REGULAR_RANK_1;
    channel.SamplingTime = ADC_SAMPLINGTIME_COMMON_1;
    if (HAL_ADC_ConfigChannel(&hadc1, &channel) != HAL_OK) {
        return false;
    }

    /* Discard the first conversion after switching inputs to allow settling. */
    for (uint32_t sample = 0U; sample <= ADC_AVERAGE_SAMPLE_COUNT; ++sample) {
        if (HAL_ADC_Start(&hadc1) != HAL_OK) {
            return false;
        }
        if (HAL_ADC_PollForConversion(&hadc1, ADC_CONVERSION_TIMEOUT_MS) != HAL_OK) {
            (void)HAL_ADC_Stop(&hadc1);
            return false;
        }

        const uint32_t value = HAL_ADC_GetValue(&hadc1);
        if (sample != 0U) sample_sum += value;
        if (HAL_ADC_Stop(&hadc1) != HAL_OK) {
            return false;
        }
    }

    *adc_raw = (uint16_t)((sample_sum + (ADC_AVERAGE_SAMPLE_COUNT / 2U)) /
                          ADC_AVERAGE_SAMPLE_COUNT);
    return true;
}

static bool CAN_TrySend(uint32_t identifier, const uint8_t payload[8])
{
    FDCAN_TxHeaderTypeDef header = {0};

    if (HAL_FDCAN_GetTxFifoFreeLevel(&hfdcan1) == 0U) {
        return false;
    }

    header.Identifier = identifier;
    header.IdType = FDCAN_STANDARD_ID;
    header.TxFrameType = FDCAN_DATA_FRAME;
    header.DataLength = FDCAN_DLC_BYTES_8;
    header.ErrorStateIndicator = FDCAN_ESI_ACTIVE;
    header.BitRateSwitch = FDCAN_BRS_OFF;
    header.FDFormat = FDCAN_CLASSIC_CAN;
    header.TxEventFifoControl = FDCAN_NO_TX_EVENTS;
    header.MessageMarker = 0U;

    return HAL_FDCAN_AddMessageToTxFifoQ(&hfdcan1, &header, payload) == HAL_OK;
}

static bool Heartbeat_TrySend(uint8_t sequence)
{
    uint8_t payload[8];

    CanProtocol_EncodeHeartbeat(payload, sequence, HAL_GetTick());

    return CAN_TrySend(CAN_ID_ENGINE_HEARTBEAT, payload);
}

static bool CoolantTemperature_TrySend(uint8_t sensor_id, uint8_t sequence)
{
    uint8_t payload[8];
    uint16_t adc_raw = 0U;
    Tx3SensorReading reading;

    const bool pre_radiator = sensor_id == CAN_SENSOR_ID_COOLANT_OUTLET;
    if (ADC1_ReadAverage(pre_radiator ? ADC_CHANNEL_0 : ADC_CHANNEL_1, &adc_raw)) {
        reading = Tx3Sensor_ConvertAdc(adc_raw);
    } else {
        reading.adc_raw = 0U;
        reading.temperature_deci_c = TX3_INVALID_TEMPERATURE_DECI_C;
        reading.status = TX3_STATUS_ADC_ERROR;
    }

    CanProtocol_EncodeCoolantTemperature(payload,
                                         sensor_id,
                                         sequence,
                                         reading.status,
                                         reading.adc_raw,
                                         reading.temperature_deci_c);

    return CAN_TrySend(pre_radiator ? CAN_ID_ENGINE_COOLANT_1 : CAN_ID_ENGINE_COOLANT_2, payload);
}

void Error_Handler(void)
{
    __disable_irq();

    for (;;) {
        HAL_GPIO_TogglePin(STATUS_LED_GPIO_Port, STATUS_LED_Pin);
        for (volatile uint32_t delay = 0U; delay < 200000U; ++delay) {
            __NOP();
        }
    }
}

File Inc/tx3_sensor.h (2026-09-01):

#ifndef VAN_CANBUS_TX3_SENSOR_H
#define VAN_CANBUS_TX3_SENSOR_H

#include <stdint.h>

/* Nominal bench hardware: 2.00 kohm + 470 ohm from 3V3 to the sensor signal. */
#define TX3_PULLUP_OHMS 2470.0F

#define TX3_ADC_MAX_COUNTS 4095U
#define TX3_ADC_OPEN_THRESHOLD 4050U
#define TX3_ADC_SHORT_THRESHOLD 16U

#define TX3_STATUS_OK 0x00U
#define TX3_STATUS_OPEN_CIRCUIT 0x01U
#define TX3_STATUS_SHORT_CIRCUIT 0x02U
#define TX3_STATUS_ADC_ERROR 0x04U
#define TX3_STATUS_CALCULATION_ERROR 0x08U

#define TX3_INVALID_TEMPERATURE_DECI_C INT16_MIN

typedef struct {
    uint16_t adc_raw;
    int16_t temperature_deci_c;
    uint8_t status;
} Tx3SensorReading;

Tx3SensorReading Tx3Sensor_ConvertAdc(uint16_t adc_raw);

#endif

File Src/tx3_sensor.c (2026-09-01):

#include "tx3_sensor.h"

#include <math.h>

/*
 * Three-point Steinhart-Hart fit for the Standard TX3/GM sensor family:
 *   0 C: 9335 ohms, 20 C: 3500 ohms, 80 C: 336 ohms.
 */
#define TX3_SH_A 0.00145590007462F
#define TX3_SH_B 0.000233293390644F
#define TX3_SH_C 0.0000000948176161592F
#define KELVIN_OFFSET 273.15F

static int16_t TemperatureToDeciC(float temperature_c)
{
    float scaled;

    if (!isfinite(temperature_c) || temperature_c < -3276.7F || temperature_c > 3276.7F) {
        return TX3_INVALID_TEMPERATURE_DECI_C;
    }

    scaled = temperature_c * 10.0F;
    scaled += (scaled >= 0.0F) ? 0.5F : -0.5F;
    return (int16_t)scaled;
}

Tx3SensorReading Tx3Sensor_ConvertAdc(uint16_t adc_raw)
{
    Tx3SensorReading reading = {
        .adc_raw = adc_raw,
        .temperature_deci_c = TX3_INVALID_TEMPERATURE_DECI_C,
        .status = TX3_STATUS_OK,
    };
    float resistance_ohms;
    float log_resistance;
    float inverse_kelvin;
    float temperature_c;

    if (adc_raw >= TX3_ADC_OPEN_THRESHOLD) {
        reading.status = TX3_STATUS_OPEN_CIRCUIT;
        return reading;
    }

    if (adc_raw <= TX3_ADC_SHORT_THRESHOLD) {
        reading.status = TX3_STATUS_SHORT_CIRCUIT;
        return reading;
    }

    resistance_ohms = TX3_PULLUP_OHMS * (float)adc_raw /
                       (float)(TX3_ADC_MAX_COUNTS - adc_raw);
    log_resistance = logf(resistance_ohms);
    inverse_kelvin = TX3_SH_A + (TX3_SH_B * log_resistance) +
                     (TX3_SH_C * log_resistance * log_resistance * log_resistance);
    temperature_c = (1.0F / inverse_kelvin) - KELVIN_OFFSET;
    reading.temperature_deci_c = TemperatureToDeciC(temperature_c);

    if (reading.temperature_deci_c == TX3_INVALID_TEMPERATURE_DECI_C) {
        reading.status = TX3_STATUS_CALCULATION_ERROR;
    }

    return reading;
}

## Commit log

2026-09-01 Add first TX3 coolant sensor telemetry
2026-09-01 Document temporary 12-pin engine harness
2026-10-05 Updated doc for power circuit
2026-10-06 added support for second temp sensor, both UI and firmware
2026-10-06 fix verify build flow
2026-10-06 added hardware suport for proto boards
    [eplzon_38x51_fit_test.step, eplzon_38x51_fit_test.stl, eplzon_38x51_tray.step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]
2026-10-08 updates to proto board fitment
    [assembled.step, carrier.step, carrier.stl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]
2026-10-16 add wifi ESP32 module for wireless CAN readouts, build cases for electronics inside the cabin
2026-10-20 update agent, add in new verify, update app dashboard, a lot more documentation, updates to new sensors,
